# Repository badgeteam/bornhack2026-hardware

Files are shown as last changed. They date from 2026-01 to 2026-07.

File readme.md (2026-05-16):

# Cyber Ægg

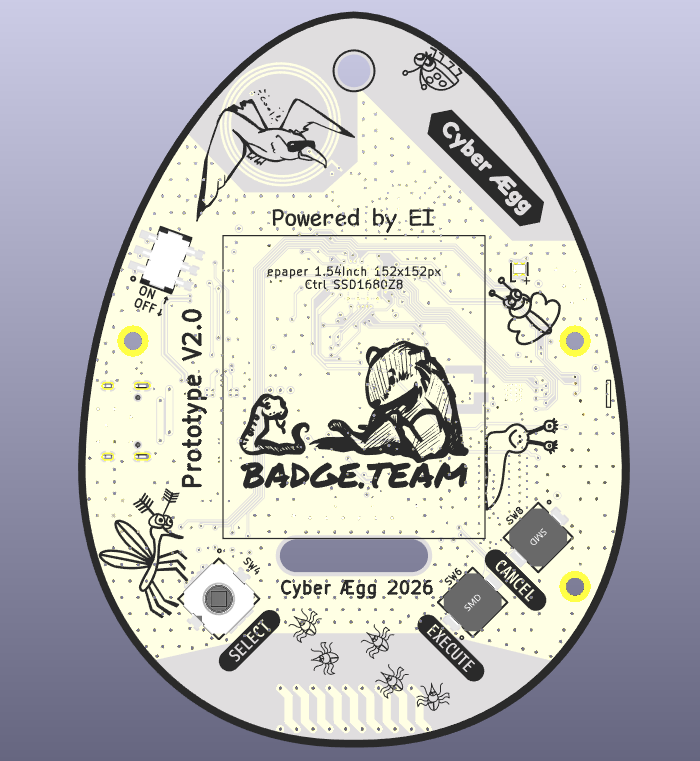
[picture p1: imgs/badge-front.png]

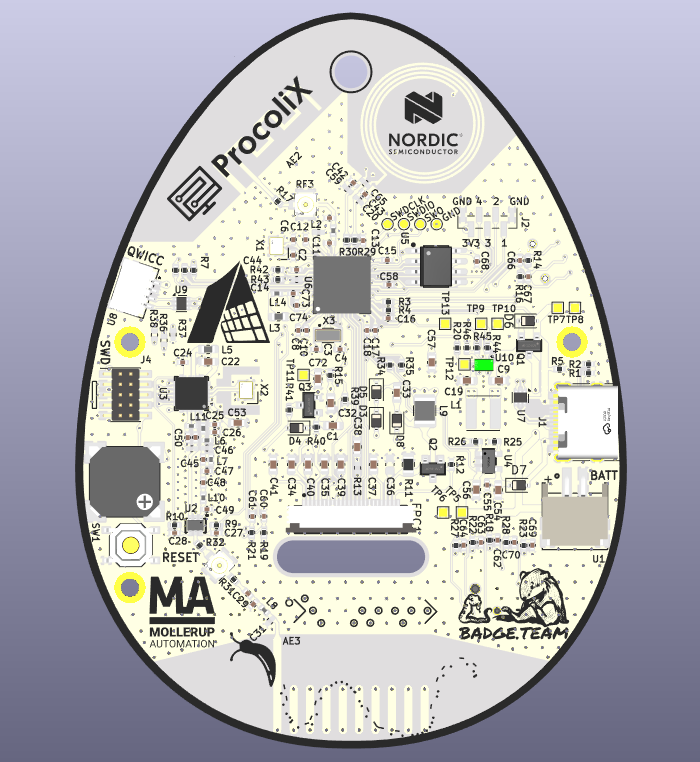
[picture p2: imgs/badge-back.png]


## Introduction

The badge is intended to be a low power LoRa device, that should be able to at least run for the whole duration of the BornHack camp on one battery charge (One week).
At least that is one of our design goals, lot's of hours chasing down power use in both the hardware and the software are still ahead of us, when measurements have been done I'll share them in the Badge.Team Discord.

At this moment the design is at prototype stage one, and is not fully developed.

For example the NFC, LoRa and Bluetooth circuits still have IPEX connectors integrated to make tuning the circuits easier.

Also certain aspects, especially the on PCB antennas should at least work, but how well, we do not know yet.

Long story short, consider this design BETA, and do not order your own boards yet. (Or if you do, you are on your own.)

## Functionality

The is designed with MeshCore in mind, to connect up to a smart phone using Bluetooth and connect to the greater MeshCore network using the on PCB LoRa circuit.

To provide some extra camp fun, we hope the communication technologies combined with the NFC tag functionality will result in some really cool location based games that will run on the badge.
For now the game ideas being worked out, and it's up to the game team of BornHack what they share.

### Display

For now the e-paper display is designed in from SWI, model number: SG0154BNS800F35HP

The display has a 1.54Inch size with 152x152 pixels.

These displays have the [SSD1680Z8](https://cdn-learn.adafruit.com/assets/assets/000/097/631/original/SSD1680_Datasheet.pdf?1607625960) controller controller IC.

### Manual input

Because the Cyber Ægg badge is inspired by the 90's Tamagotchi egg shaped game, the buttons are named the same.

| button name | function |
| --- | --- |
| Select | Navigate through the menu options |
| Execute | Start the option under the cursor |
| Cancel | Cancel current operation |

In order to make navigation a more intuitive, the select button has been upgraded to a joystick + button.

### Bluetooth

The Bluetooth implementation on this board is provided by the NRF52840 MCU.
Texas instruments has released a design for a 2.4GHz antenna, the antenna is provided as a Footprint included with Kicad 9.0.

#### BlueTooth Antenna

Bluetooth is using 2.4GHz, and a PCB antenna suitable for this frequency band is integrated into the PCB.
The design used is available in KiCAD 9 in the standard library and is originally by Texas instruments.

The documentation for the antenna can be found here : [swra228.pdf](https://www.ti.com/lit/an/swra228c/swra228c.pdf)

### LoRa

LoRa is provided by a separate SX1262 IC, with a tuning circuit as specified by the data sheet and implementation notes provided by Semtech.

The document that specifies the layout/balun/matching circuit for the sx1262 is named *"AN1200.54"* and can be found at [this page](https://www.semtech.com/products/wireless-rf/lora-connect/sx1261)

#### Lora Antenna

The LoRa antenna is also a Texas instruments design, the specifications can be found here [swra416](https://www.ti.com/lit/an/swra416/swra416.pdf)

### NFC

NRF is again provided by a PHY in the NRF82840 core, which drives a resonant circuit consisting of 2 (eventually) capacitors, and a CPB coil.

The NRF52840 only supports TAG functionality no reader functionality.

The coil in this design has a inductance of around 2.8uH, which together with the capacitors and the paracytics (both capacitance and inductance) should form a tank circuit that matches the 13.56MHz for interacting with an NRC reader.

### QWIIC

The QWIIC port is a standardized connector utilizing I2C, it's included on the badge because many boards have been produced for this [standard](https://www.sparkfun.com/qwiic) setup by Sparkfun.

Pins used for the SDA and SCL pins are listed below.

Two 10k pull up resistors are provided on the board, when the capacitance is too high on the I2C lines, the internal pull-ups can also be enabled (the provide an extra 10k pull-up resistance).

## Production

!! Very important: The vias on the board must be filled with epoxy and capped for proper soldering. !!

### JLCPCB production settings

#### PCB production settings

| Item | Value |
| :--- | :--- |
| Base Material | FR-3 |
| Product type | Industrial / Consumer electronics  |
| PCB Thickness | 1.6mm |
| Material Type | FR4 TG135 |
| Gold thickness | 1 U" |
| Outer Copper Weight | 1 oz |
| Inner Copper Weight | 0.5 oz |
| Surface Finish | ENIG |
| Specify Stackup | JLC0461H-7628 (Prepreg 0.21mm, Core 1.065mm) |
| Impedance Control | No requirement |
| Via Covering | Epoxy Filled & Capped |
| Via Plating Method | Horizontal Electroless Copper Plating |
| Min via hole size/diameter | 0.2mm |
| Board outline Tolerance | 0.2mm |
 
#### PCBA production settings

| Item | Value |
| :--- | :---- |
| PCBA Type | Standard |
| Assembly Side | Both Sides |
| Parts Selection | By Customer |

## Pinout

| Ball (aQFN73) | nRF pin | Pin type(s) | Project net  | Project function |
| :--- | :--- | :--- | :--- | :--- |
| A12 | P0.02 AIN0 | Digital I/O Analog input | LED_BLUE | LED blue (active low, GPIO output) |
| B13 | P0.03 AIN1 | Digital I/O Analog input | LORA_MISO | LoRa (SX1262) SPI MISO (GPIO input) |
| J1 | P0.04 AIN2 | Digital I/O Analog input | LORA_RF_SW | LoRa RF switch control (GPIO output) |
| K2 | P0.05 AIN3 | Digital I/O Analog input | BAT_CHARGE | Charge status: low when charging (GPIO input) |
| L1 | P0.06 | Digital I/O | BTN_CANCEL | Button: cancel (active low, GPIO input) |
| M2 | P0.07 | Digital I/O | BAT_V_READ | Battery read enable: pull low to read VBAT (GPIO output) |
| N1 | P0.08 | Digital I/O | EPD_SCK | EPD (SSD1675) SPI SCK (GPIO output) |
| M24 | P0.09 NFC1 | NFC I/O | NFC1 | NFC antenna connection |
| L24 | P0.10 NFC2 | NFC I/O | NFC2 | NFC antenna connection |
| U1 | P0.11 | Digital I/O | EPD_RESET | EPD (SSD1675) reset (GPIO output) |
| V2 | P0.12 | Digital I/O | EPD_DC | EPD (SSD1675) data/command (GPIO output) |
| W1 | P0.13 | Digital I/O | BUZZER | Buzzer square wave output (PWM/GPIO output) |
| X2 | P0.14 | Digital I/O | EPD_BUSY | EPD (SSD1675) busy signal (GPIO input) |
| AC12 | P0.15 | Digital I/O | GPIO_1 | General purpose I/O 1 |
| AB13 | P0.16 | Digital I/O | GPIO_2 | General purpose I/O 2 |
| AC11 | P0.17 | Digital O | PS_SYNC | Power mode buck/boost hi/low power mode |
| AC13 | P0.18 nRESET | Digital O | MCU_RESET | nRESET (active low) |
| AB11 | P0.19 | Digital I/O | GPIO_3 | General purpose I/O 3 |
| AC9 | P0.20 | Digital I/O (QSPI) | FLASH_IO0 | QSPI Flash IO0/D0 |
| AB9 | P0.21 | Digital I/O (QSPI) | FLASH_SCK | QSPI Flash clock (GPIO output) |
| AC7 | P0.22 | Digital I/O (QSPI) | FLASH_IO2 | QSPI Flash IO2/D2 |
| AB7 | P0.23 | Digital I/O (QSPI) | FLASH_IO3 | QSPI Flash IO3/D3 |
| AC5 | P0.24 | Digital I/O (QSPI) | FLASH_IO1 | QSPI Flash IO1/D1 |
| AB5 | P0.25 | Digital I/O (QSPI) | FLASH_CSN | QSPI Flash chip select (active low, GPIO output) |
| G1 | P0.26 | Digital I/O | BTN_EXECUTE  | Button: execute (active low, GPIO input) |
| H2 | P0.27 | Digital I/O | EPD_MOSI | EPD (SDD1675) SPI MOSI (GPIO output) |
| B11 | P0.28 AIN4 | Digital I/O Analog input | LORA_BUSY | LoRa (SX1262) busy (GPIO input) |
| A10 | P0.29 AIN5 | Digital I/O Analog input | LORA_DIO1 | LoRa (SX1262) DIO1 IRQ (GPIO input) |
| B9 | P0.30 AIN6 | Digital I/O Analog input | LORA_RST | LoRa (SX1262) reset (GPIO output) |
| A8 | P0.31 AIN7 | Digital I/O Analog input | VBAT_V | Battery voltage sense (ADC input) |
| AD22 | P1.00 | SWD | P1.00_SWO | SWO pin SWD NRF52840 |
| Y23 | P1.01 | Digital I/O | JOY_RIGHT | Joystick: right (active low, GPIO input) |
| W24 | P1.02 | Digital I/O | JOY_FIRE | Joystick: fire (active low, GPIO input) |
| V24 | P1.03 | Digital I/O | JOY_DOWN | Joystick: down (active low, GPIO input) |
| U24 | P1.04 | Digital I/O | JOY_UP | Joystick: up (active low, GPIO input) |
| T23 | P1.05 | Digital I/O | JOY_LEFT | Joystick: left (active low, GPIO input) |
| P23 | P1.07 | Digital I/O | LED_RED | LED red (active low, GPIO output) |
| P2 | P1.08 | Digital I/O | EPD_MOSI | EPD (SSD1675) MISO/MOSI line EPD |
| R1 | P1.09 | Digital I/O | EPD_CSN | EPD (SSD1675) SPI CSN (active low, GPIO output) |
| A20 | P1.10 | Digital I/O | QWIIC_SDA | Qwiic I²C SDA (open-drain) |
| B19 | P1.11 | Digital I/O | QWIIC_SCL | Qwiic I²C SCL (open-drain) |
| B17 | P1.12 | Digital I/O | LORA_NSS | LoRa (SX1262) SPI NSS/CS (active low, GPIO output) |
| A16 | P1.13 | Digital I/O | LORA_SCK | LoRa (SX1262) SPI SCK (GPIO output) |
| B15 | P1.14 | Digital I/O | LORA_MOSI | LoRa (SX1262) SPI MOSI (GPIO output) |
| A14 | P1.15 | Digital I/O | LED_GREEN | LED green (active low, GPIO output) |
| AD6 | D+ | USB | USB_D+ | USB data + |
| AD4 | D- | USB | USB_D- | USB data - |

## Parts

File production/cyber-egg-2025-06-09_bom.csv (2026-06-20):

Designator | Footprint | Quantity | Value | LCSC Part #
BUZZER1 | BUZ-SMD_4P-L8.5-W8.5-P8.50-BR | 1 | MLT-8530 | C94599
C1, C33, C34, C35, C37, C38, C39, C40, C53, C72 | 0603 | 10 | 1uF | C5199872
C10, C24, C55, C58, C60, C61, C62, C63, C64, C68, C69, C70 | 0402 | 12 | 100nF | C1525
C12 | 0402 | 1 | 100pF | C1546
C13 | 0402 | 1 | 820pF | C1543
C15, C18, C44, C66, C67, C8 | 0402 | 6 | 2.2uF | C12530
C16, C17 | 0402 | 2 | 4.7uF | C23733
C19, C57 | 0603 | 2 | 22uF | C59461
C2, C6 | 0402 | 2 | 18pF | C1549
C22, C41 | 0603 | 2 | 470nF | C1623
C25, C73 | 0402 | 2 | 47nF | C82219
C26, C29 | 0402 | 2 | 47pF | C472454
C27, C28 | 0402 | 2 | 1nF | C1523
C3, C4 | 0402 | 2 | 12pF | C1547
C30, C50 | 0402 | 2 | 1.8pF | C22374861
C32 | 0603 | 1 | 4.7uF | C69335
C42, C43 | 0402 | 2 | 68pF | C389103
C45 | 0402 | 1 | 3.3pF | C2941931
C47 | 0402 | 1 | 5.6pF | C16193755
C48 | 0402 | 1 | 39pF | C86288
C49 | 0402 | 1 | 2.2pF | C325452
C5 | 0402 | 1 | .5pF | C1544
C51 | 0402 | 1 | 2.4pF | C48346
C54, C56, C9 | 0603 | 3 | 10uF | C19702
C7 | 0402 | 1 | .8pF | C285068
C74 | 0402 | 1 | 1uF | C52923
D3, D5, D8 | D_SOD-323 | 3 | B0530WS | C22466873
D4, D6, D7 | D_SOD-323 | 3 | 1N5819WS | C191023
FPC1 | FPC-SMD_24P-P0.50_GT-F0501SR10-24S1101 | 1 | GT-F0501SR10-24S1101 | C22380687
J1 | USB_C_Receptacle_HRO_TYPE-C-31-M-12 | 1 | USB device | C165948
J4 | SWD_PinHeader_2x05_P1.27mm_Vertical_SMD | 1 | Conn_02x05_Odd_Even | C27985146
L1 | L_Vishay_IFSC-1515AH_4x4x1.8mm | 1 | 0.47uH A-sat 5.4 DCR 7.6 mOhm | C7497069
L10, L2 | 0402 | 2 | 4.7nH | C86065
L11, R17, R29, R3, R30, R31, R32, R4 | 0402 | 8 | 0 | C17168
L12, L14 | 0402 | 2 | 15nH | C381880
L3 | 0603 | 1 | 10uH | C1035
L5 | 0603 | 1 | 15uH | C486329
L6 | 0402 | 1 | 47nH | C27151
L7 | 0402 | 1 | 2.5nH | C778764
L8 | 0402 | 1 | 7.5nH | C98001
L9 | 1210 | 1 | 47uH | C83083
LED1 | LED-ARRAY-SMD_4P-L1.6-W1.5-BR_XL-1615RGBC-RF | 1 | XL-1615RGBC-RF | C965840
Q1 | SOT-23-3_L2.9-W1.3-P1.90-LS2.4-BR | 1 | JSM2301S | C916399
Q2 | SOT-23-3_L2.9-W1.3-P1.90-LS2.4-BR | 1 | AP2302B | C406812
Q3 | SOT-23-3_L2.9-W1.3-P1.90-LS2.4-BR | 1 | SI2302_C5296725 | C5296725
R1, R2 | 0402 | 2 | 5k1 | C25905
R10, R41, R47, R9 | 0402 | 4 | 100 | C25076
R11 | 0805 | 1 | 2.2 | C2907304
R12, R5 | 0402 | 2 | 100k | C25741
R14, R16, R24 | 0402 | 3 | 1k | C11702
R15 | 0402 | 1 | 47k | C25792
R18, R19, R21, R22, R23, R26, R27, R28, R7 | 0402 | 9 | 10k | C25744
R20 | 0402 | 1 | 3.3k | C25890
R25, R6, R8 | 0402 | 3 | 2k | C4109
R34, R39, R40, R44 | 0402 | 4 | 1M | C26083
R35 | 0402 | 1 | 510k | C25564
R42, R43 | 0402 | 2 | 4.7k | C25900
R45 | 0402 | 1 | 511k | C64042
R46 | 0402 | 1 | 91k | C4147
RF1, RF3 | IPEX-SMD_3P-L2.6-W2.6-LS3.0_RF1200001R | 2 | A-IPEX1-1.25A | C22467595
SW1 | SW-SMD_4P-L5.1-W5.1-P3.70-LS6.5-TL_H1.5 | 1 | RESET | C318884
SW3 | SW-SMD_MS-22D28-G020 | 1 | MS-22D28-G020 | C963205
SW4 | SW-SMD_6P-L7.0-W7.0-P1.40-LS7.4-TL | 1 | 7*7*5-6P WX | C2858286
SW6, SW8 | KEY-SMD_2P-L6.0-W6.0-P6.00 | 2 | TS3425PA 160GF 098 | C115348
U1 | CONN-SMD_PH-2AWB | 1 | PH-2AWB | C20598817
U10 | DSBGA-15_L2.3-W1.3-R5-C3-P0.40-TL | 1 | TPS63805YFFR | C2879615
U2 | SOT-363-6_L2.0-W1.3-P0.65-LS2.1-BL | 1 | ZHHXDZ HXCKRF2179MM26-C4 | C49010109
U3 | QFN-24_L4.0-W4.0-P0.50-BL-EP2.6 | 1 | SX1262IMLTRT | C191341
U4 | SOT-23-5_L2.9-W1.6-P0.95-LS2.8-BL | 1 | XT4054K421MR-G | C141405
U5 | SOIC-8_L4.9-W3.9-P1.27-LS6.0-BL | 1 | ZD25WQ16CTIGT | C5353550
U6 | XCVR_NRF52840-QIAA-R | 1 | NRF52840-QIAA-R | C190794
U7, U9 | SOT-666 | 2 | USBLC6-2P6 | C22390016
U8 | CONN-SMD_HCZZ0032-4 | 1 | HCZZ0032-4 | C7433425
X1, X2 | CRYSTAL-SMD_4P-L2.0-W1.6-BL | 2 | S201632M10PF10PPM 32MHz | C7420782
X3 | Crystal_SMD_3215-2Pin_3.2x1.5mm | 1 | 32.768KHz | C95361

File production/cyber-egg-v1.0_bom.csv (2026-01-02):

Designator | Footprint | Quantity | Value | LCSC Part #
C1, C27, C28 | 0402 | 3 | 1nF | C1523
C10, C14, C24, C55, C57, C64, C68 | 0402 | 7 | 100nF | C1525
C12 | 0402 | 1 | 100pF | C1546
C13 | 0402 | 1 | 820pF | C1543
C15, C16, C17, C18, C19, C44, C66, C67, C8 | 0402 | 9 | 2.2uF | C12530
C2, C21, C23, C6 | 0402 | 4 | 10pF | C32949
C22 | 0603 | 1 | 470nF | C1623
C25, C73 | 0402 | 2 | 47nF | C82219
C26, C29 | 0402 | 2 | 47pF | C472454
C3, C4 | 0402 | 2 | 10n | C1524
C30, C31 | 0402 | 2 | 3.6pF | C52052
C32 | 0603 | 1 | 4.7uF | C69335
C33, C34, C35, C36, C37, C38, C39, C40, C53, C72, C74 | 0603 | 11 | 1uF | C5199872
C41 | 0603 | 1 | 470n | C1623
C42, C43 | 0402 | 2 | 12pF | C161304
C45 | 0402 | 1 | 3pF | C41361091
C47 | 0402 | 1 | 5.6pF | C16193755
C48 | 0402 | 1 | 39pF | C86288
C49, C50 | 0402 | 2 | 1.8pF | C22374861
C5 | 0402 | 1 | .5pF | C1544
C51 | 0402 | 1 | 2.4pF | C48346
C54, C56, C60, C61 | 0603 | 4 | 10uF | C19702
C58, C62, C63 | 0805 | 3 | 22uF | C45783
C69, L11, R20, R29, R30, R31, R32 | 0402 | 7 | 0 | C17168
C7 | 0402 | 1 | .8pF | C285068
D1 | D_SOD-323 | 1 | ESD prot. | C22363742
D2 | D_SMA | 1 | B160_13F | C24784
D23, D3, D4, D5 | D_SOD-323 | 4 | NSR0320MW2T1G | C48192
J1 | USB_C_Receptacle_HRO_TYPE-C-31-M-12 | 1 | USB device | C165948
J2 | FPC-SMD_FH12-24S-0.5SH-55 | 1 | E-Paper | C202112
J9 | CONN-SMD_S2B-ZR-SM4A | 1 | Battery | C265329
L1 | ANT-SMD_L3.1-W1.6 | 1 | RFECA3216060A1T | C127620
L10, L2 | 0402 | 2 | 4.7nH | C963987
L12 | 0402 | 1 | 15nH | C381880
L13 | ANT-SMD_L15.0-W3.0 | 1 | 866MHz LoRa antenna | C41368044
L14 | 0402 | 1 | 15nH | C27143
L3 | 0603 | 1 | 10uH | C194437
L4 | IND-SMD_L6.0-W6.0 | 1 | CMLW6028S1R5MST | C431354
L5 | 0603 | 1 | 15uH | C486329
L6 | 0402 | 1 | 47nH | C27151
L7 | 0402 | 1 | 2.5nH | C778764
L8 | 0402 | 1 | 8.2nH | C98003
L9 | 1210 | 1 | 47uH | C83083
LED1 | LED-ARRAY-SMD_4P-L1.6-W1.5-BR_XL-1615RGBC-RF | 1 | XL-1615RGBC-RF | C965840
Q1 | SOT-23-3_L2.9-W1.3-P1.90-LS2.4-BR | 1 | JSM2301S | C916399
Q2 | SOT-23-3_L2.9-W1.3-P1.90-LS2.4-BR | 1 | AP2302B | C406812
R1, R2 | 0402 | 2 | 5k1 | C25905
R10, R9 | 0402 | 2 | 100 | C25076
R11 | 0805 | 1 | 2.2 | C2907304
R12, R5 | 0402 | 2 | 100k | C25530
R14, R16 | 0402 | 2 | 1k | C11702
R15, R18, R19, R21, R22, R23, R26, R27, R28, R7 | 0402 | 10 | 10k | C25744
R17, R33 | 0402 | 2 | 1M | C26083
R24 | 0402 | 1 | 180k | C2909325
R25, R6, R8 | 0402 | 3 | 2k | C4109
R3, R4 | 0402 | 2 | 33 | C25105
RF1, RF2, RF3 | IPEX-SMD_3P-L2.6-W2.6-LS3.0_RF1200001R | 3 | A-IPEX1-1.25A | C22467595
SW1 | SW-SMD_4P-L5.1-W5.1-P3.70-LS6.5-TL_H1.5 | 1 | TS-1187A-B-A-B | C318884
SW2 | SW-SMD_3P-P1.50_L2.7-W6.6 | 1 | SK-3296S-01-L1 | C319020
SW3 | SW-SMD_SKRHABE010 | 1 | SKRHABE010 | C139794
SW6, SW8 | KEY-SMD_2P-L6.0-W6.0-P6.00 | 2 | TS3425PA 160GF 098 | C115348
U2 | SOT-363-6_L2.0-W1.3-P0.65-LS2.1-BL | 1 | TPE4259-63 | C47117600
U3 | QFN-24_L4.0-W4.0-P0.50-BL-EP2.6 | 1 | SX1262IMLTRT | C191341
U4 | SOT-23-5_L2.9-W1.6-P0.95-LS2.8-BL | 1 | XT4054K421MR-G | C141405
U5 | SOIC-8_L4.9-W3.9-P1.27-LS6.0-BL | 1 | ZD25WQ16CTIGT | C5353550
U6 | XCVR_NRF52840-QIAA-R | 1 | NRF52840-QIAA-R | C190794
U7 | VSON-14_L4.0-W3.0-P0.50-BL-EP_TI_DSJ | 1 | TPS63020DSJR | C15483
X1, X2 | CRYSTAL-SMD_4P-L2.0-W1.6-BL | 2 | S201632M10PF10PPM | C7420782
X3 | Crystal_SMD_3215-2Pin_3.2x1.5mm | 1 | 32.768KHz | C95361

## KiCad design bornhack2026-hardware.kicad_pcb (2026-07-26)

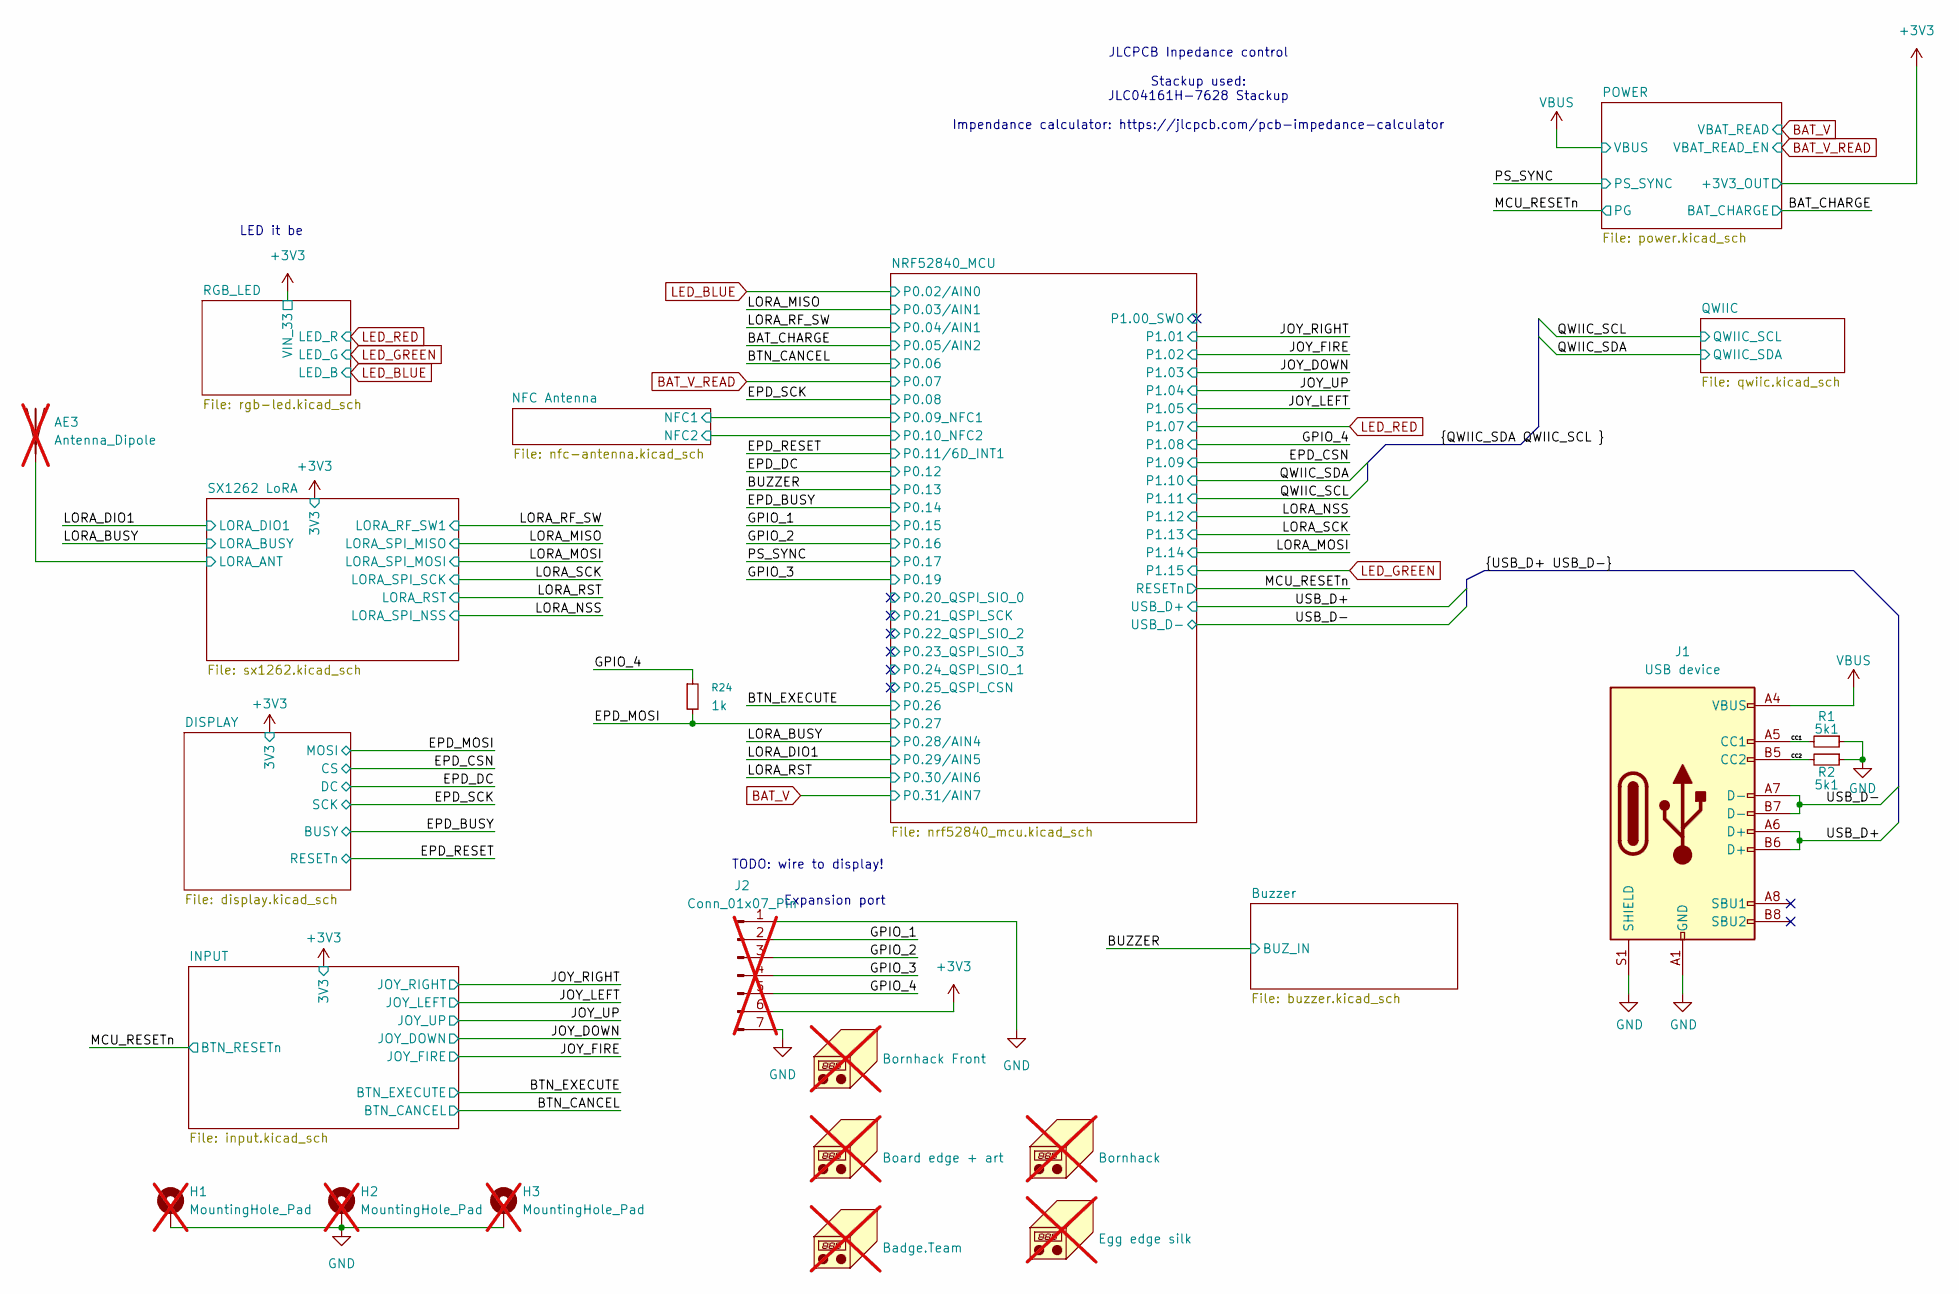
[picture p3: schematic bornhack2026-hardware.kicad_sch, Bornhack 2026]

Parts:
AE3: Antenna_Dipole; Texas_SWRA416_868MHz_915MHz_right_v2; not fitted
H1, H2, H3: MountingHole_Pad; MountingHole_2.2mm_M2_DIN965_Pad; not fitted
J1: USB device; USB_C_Receptacle_HRO_TYPE-C-31-M-12; LCSC C165948
J2: Conn_01x07_Pin; PinHeader_1x07_P1.00mm_Vertical_SMD_Pin1Left; not fitted
N1: Board edge + art; white-egg-svg2shenzhen; not fitted
N2: Badge.Team; stamp; not fitted
N3: Bornhack; bornhack-logo-10mm; not fitted
N4: Egg edge silk; egg-edge-silk; not fitted
N5: Bornhack Front; bornhack-logo-10mm; not fitted
R1, R2: 5k1; R_0402_1005Metric; LCSC C25905
R24: 1k; R_0402_1005Metric; LCSC C11702

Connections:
+3V3: J2.6; also elsewhere on the board
/CC1: J1.A5 (CC1), R1.2
/CC2: J1.B5 (CC2), R2.2
/EPD_MOSI: R24.2; also elsewhere on the board
/GPIO_1: J2.2; also elsewhere on the board
/GPIO_2: J2.3; also elsewhere on the board
/GPIO_3: J2.4; also elsewhere on the board
/GPIO_4: J2.5, R24.1; also elsewhere on the board
/SX1262 LoRA/LORA_ANT: AE3.1 (A_1); also elsewhere on the board
/USB_D+: J1.A6 (D+), J1.B6 (D+); also elsewhere on the board
/USB_D-: J1.A7 (D-), J1.B7 (D-); also elsewhere on the board
GND: H1.1 (1_1), H2.1 (1_1), H3.1 (1_1), J1.A1 (GND), J1.A12 (GND), J1.B1 (GND), J1.B12 (GND), J1.S1 (SHIELD), J2.1, J2.7, R1.1, R2.1; also elsewhere on the board
VBUS: J1.A4 (VBUS), J1.A9 (VBUS), J1.B4 (VBUS), J1.B9 (VBUS); also elsewhere on the board

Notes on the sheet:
TODO: wire to display!
JLCPCB Inpedance control Stackup used: JLC04161H-7628 Stackup Impendance calculator: https://jlcpcb.com/pcb-impedance-calculator
LED it be
Expansion port

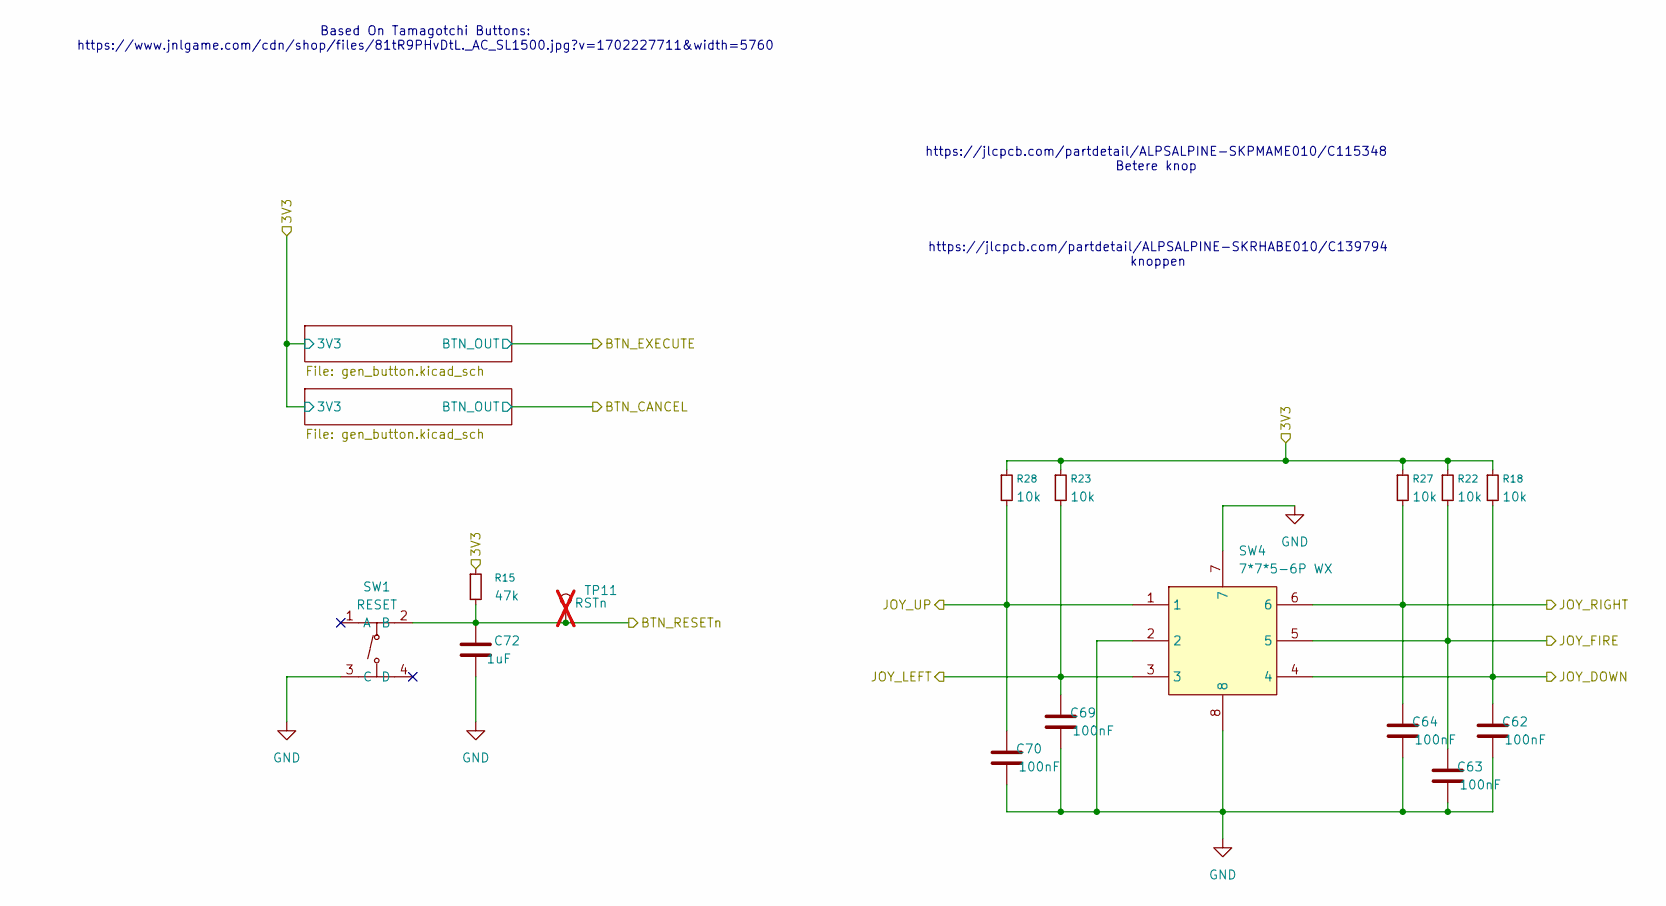
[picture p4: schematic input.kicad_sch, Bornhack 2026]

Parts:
C62, C63, C64, C69, C70: 100nF; C_0402_1005Metric; LCSC C1525
C72: 1uF; C_0603_1608Metric; LCSC C5199872
R15: 47k; R_0402_1005Metric; LCSC C25792
R18, R22, R23, R27, R28: 10k; R_0402_1005Metric; LCSC C25744
SW1: RESET; SW-SMD_4P-L5.1-W5.1-P3.70-LS6.5-TL_H1.5; LCSC Part C318884
SW4: 7*7*5-6P WX; SW-SMD_6P-L7.0-W7.0-P1.40-LS7.4-TL; LCSC C2858286
TP11: TestPoint; TestPoint_Pad_1.0x1.0mm; not fitted

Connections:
+3V3: R15.1, R18.1, R22.1, R23.1, R27.1, R28.1; also elsewhere on the board
/JOY_DOWN: C62.2, R18.2, SW4.4; also elsewhere on the board
/JOY_FIRE: C63.2, R22.2, SW4.5; also elsewhere on the board
/JOY_LEFT: C69.2, R23.2, SW4.3; also elsewhere on the board
/JOY_RIGHT: C64.2, R27.2, SW4.6; also elsewhere on the board
/JOY_UP: C70.2, R28.2, SW4.1; also elsewhere on the board
/MCU_RESETn: C72.2, R15.2, SW1.2 (B), TP11.1 (1_1); also elsewhere on the board
GND: C62.1, C63.1, C64.1, C69.1, C70.1, C72.1, SW1.3 (C), SW4.2, SW4.7, SW4.8; also elsewhere on the board

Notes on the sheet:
https://jlcpcb.com/partdetail/ALPSALPINE-SKPMAME010/C115348 Betere knop
Based On Tamagotchi Buttons: https://www.jnlgame.com/cdn/shop/files/81tR9PHvDtL._AC_SL1500.jpg?v=1702227711&width=5760
https://jlcpcb.com/partdetail/ALPSALPINE-SKRHABE010/C139794 knoppen

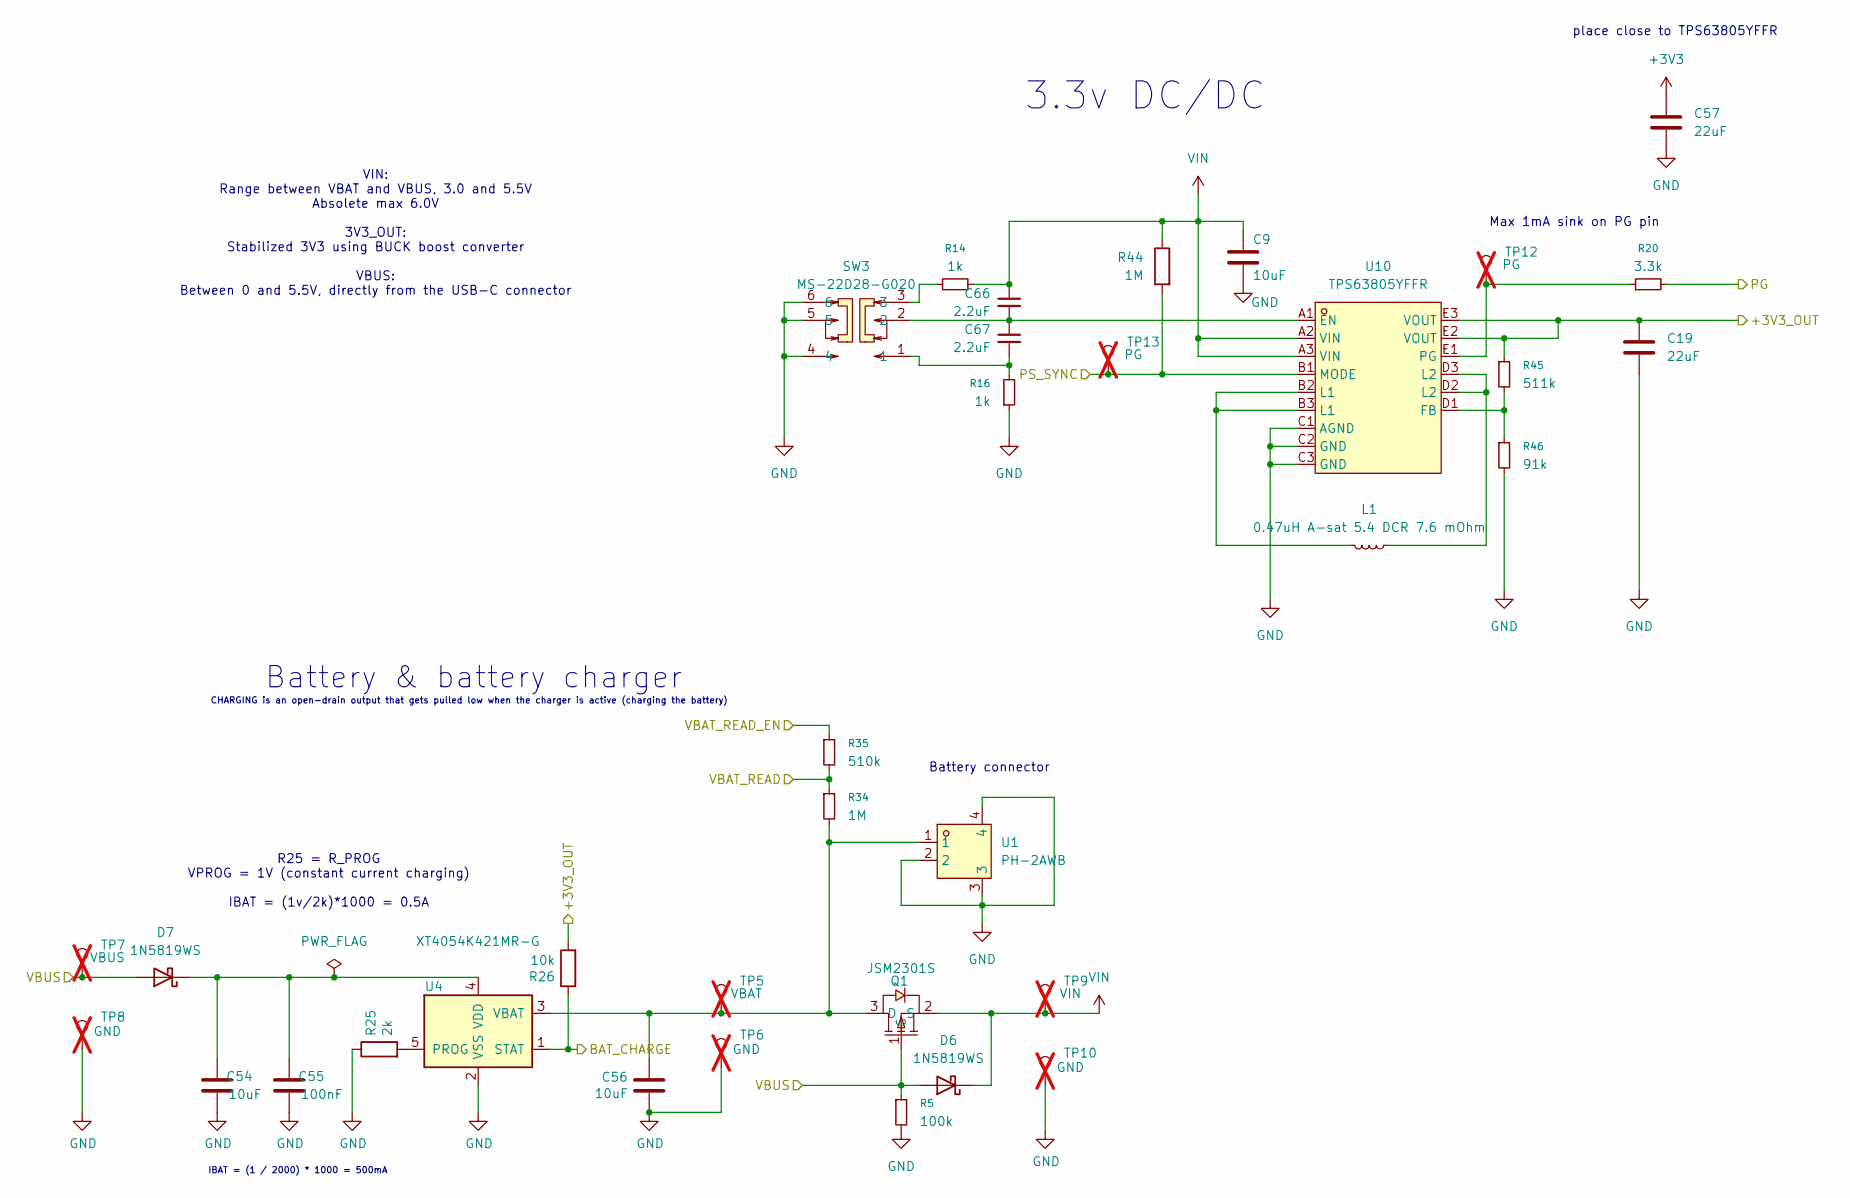
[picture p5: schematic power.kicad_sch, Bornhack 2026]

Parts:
C9, C54, C56: 10uF; C_0603_1608Metric; LCSC C19702
C19, C57: 22uF; C_0603_1608Metric; LCSC C59461
C55: 100nF; C_0402_1005Metric; LCSC C1525
C66, C67: 2.2uF; C_0402_1005Metric; LCSC C12530
D6, D7: 1N5819WS; D_SOD-323; LCSC C191023
L1: 0.47uH A-sat 5.4 DCR 7.6 mOhm; L_Vishay_IFSC-1515AH_4x4x1.8mm; LCSC C7497069
Q1: JSM2301S; SOT-23-3_L2.9-W1.3-P1.90-LS2.4-BR; LCSC Part C916399
R5: 100k; R_0402_1005Metric; LCSC C25741
R14, R16: 1k; R_0402_1005Metric; LCSC C11702
R20: 3.3k; R_0402_1005Metric; LCSC C25890
R25: 2k; R_0402_1005Metric; LCSC C4109
R26: 10k; R_0402_1005Metric; LCSC C25744
R34, R44: 1M; R_0402_1005Metric; LCSC C26083
R35: 510k; R_0402_1005Metric; LCSC C25564
R45: 511k; R_0402_1005Metric; LCSC C64042
R46: 91k; R_0402_1005Metric; LCSC C4147
SW3: MS-22D28-G020; SW-SMD_MS-22D28-G020; LCSC Part C963205
TP5, TP6, TP7, TP8, TP9, TP10, TP12, TP13: TestPoint; TestPoint_Pad_1.0x1.0mm; not fitted
U1: PH-2AWB; CONN-SMD_PH-2AWB; LCSC Part C20598817
U4: XT4054K421MR-G; SOT-23-5_L2.9-W1.6-P0.95-LS2.8-BL; LCSC C141405
U10: TPS63805YFFR; DSBGA-15_L2.3-W1.3-R5-C3-P0.40-TL; LCSC Part C2879615

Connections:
+3V3: C19.1, C57.1, R26.2, R45.1, U10.E2 (VOUT), U10.E3 (VOUT); also elsewhere on the board
/BAT_CHARGE: R26.1, U4.1 (STAT); also elsewhere on the board
/MCU_RESETn: R20.2; also elsewhere on the board
/PS_SYNC: R44.2, TP13.1 (1_1), U10.B1 (MODE); also elsewhere on the board
BAT_V: R34.1, R35.2; also elsewhere on the board
BAT_V_READ: R35.1; also elsewhere on the board
GND: C9.2, C19.2, C54.1, C55.1, C56.2, C57.2, R5.2, R16.1, R25.1, R46.2, SW3.4, SW3.5, SW3.6, TP6.1 (1_1), TP8.1 (1_1), TP10.1 (1_1), U1.2, U1.3, U1.4, U4.2 (VSS), U10.C1 (AGND), U10.C2 (GND), U10.C3 (GND); also elsewhere on the board
unnamed: C67.2, R16.2, SW3.1
unnamed: C54.2, C55.2, D7.1 (K), U4.4 (VDD)
unnamed: L1.1, U10.D2 (L2), U10.D3 (L2)
unnamed: L1.2, U10.B2 (L1), U10.B3 (L1)
unnamed: C56.1, Q1.3 (D), R34.2, TP5.1 (1_1), U1.1, U4.3 (VBAT)
unnamed: R14.2, SW3.3
unnamed: R25.2, U4.5 (PROG)
unnamed: C66.2, C67.1, SW3.2, U10.A1 (EN)
unnamed: R45.2, R46.1, U10.D1 (FB)
unnamed: R20.1, TP12.1 (1_1), U10.E1 (PG)
VBUS: D6.2 (A), D7.2 (A), Q1.1 (G), R5.1, TP7.1 (1_1); also elsewhere on the board
VIN: C9.1, C66.1, D6.1 (K), Q1.2 (S), R14.1, R44.1, TP9.1 (1_1), U10.A2 (VIN), U10.A3 (VIN)

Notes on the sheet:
CHARGING is an open-drain output that gets pulled low when the charger is active (charging the battery)
Max 1mA sink on PG pin
IBAT = (1 / 2000) * 1000 = 500mA
3.3v DC/DC
Battery & battery charger
Battery connector
VIN: Range between VBAT and VBUS, 3.0 and 5.5V Absolete max 6.0V 3V3_OUT: Stabilized 3V3 using BUCK boost converter VBUS: Between 0 and 5.5V, directly from the USB-C connector
place close to TPS63805YFFR
R25 = R_PROG VPROG = 1V (constant current charging) IBAT = (1v/2k)*1000 = 0.5A

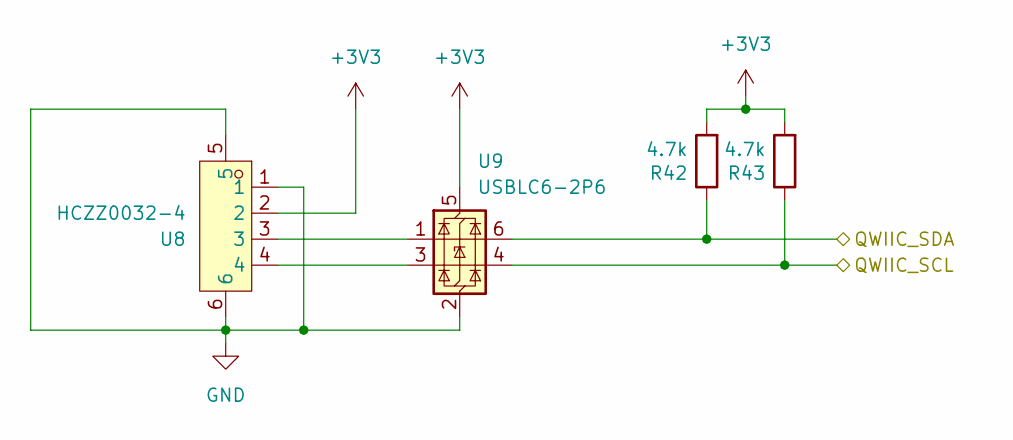
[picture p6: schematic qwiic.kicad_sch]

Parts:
R42, R43: 4.7k; R_0402_1005Metric; LCSC C25900
U8: HCZZ0032-4; CONN-SMD_HCZZ0032-4; LCSC Part C7433425
U9: USBLC6-2P6; SOT-666; LCSC C22390016

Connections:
+3V3: R42.2, R43.2, U8.2, U9.5 (VBUS); also elsewhere on the board
/QWIIC_SCL: R43.1, U9.4 (I/O2); also elsewhere on the board
/QWIIC_SDA: R42.1, U9.6 (I/O1); also elsewhere on the board
GND: U8.1, U8.5, U8.6, U9.2 (GND); also elsewhere on the board
unnamed: U8.3, U9.1 (I/O1)
unnamed: U8.4, U9.3 (I/O2)

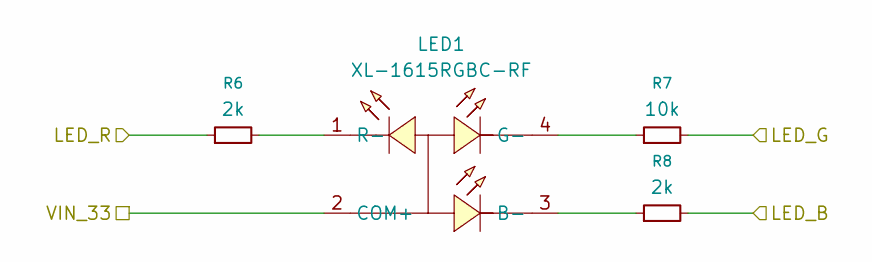
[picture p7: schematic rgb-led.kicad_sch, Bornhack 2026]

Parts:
LED1: XL-1615RGBC-RF; LED-ARRAY-SMD_4P-L1.6-W1.5-BR_XL-1615RGBC-RF; LCSC Part C965840
R6, R8: 2k; R_0402_1005Metric; LCSC C4109
R7: 10k; R_0402_1005Metric; LCSC C25744

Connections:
+3V3: LED1.2 (COM+); also elsewhere on the board
LED_BLUE: R8.2; also elsewhere on the board
LED_GREEN: R7.2; also elsewhere on the board
LED_RED: R6.1; also elsewhere on the board
unnamed: LED1.3 (B-), R8.1
unnamed: LED1.4 (G-), R7.1
unnamed: LED1.1 (R-), R6.2

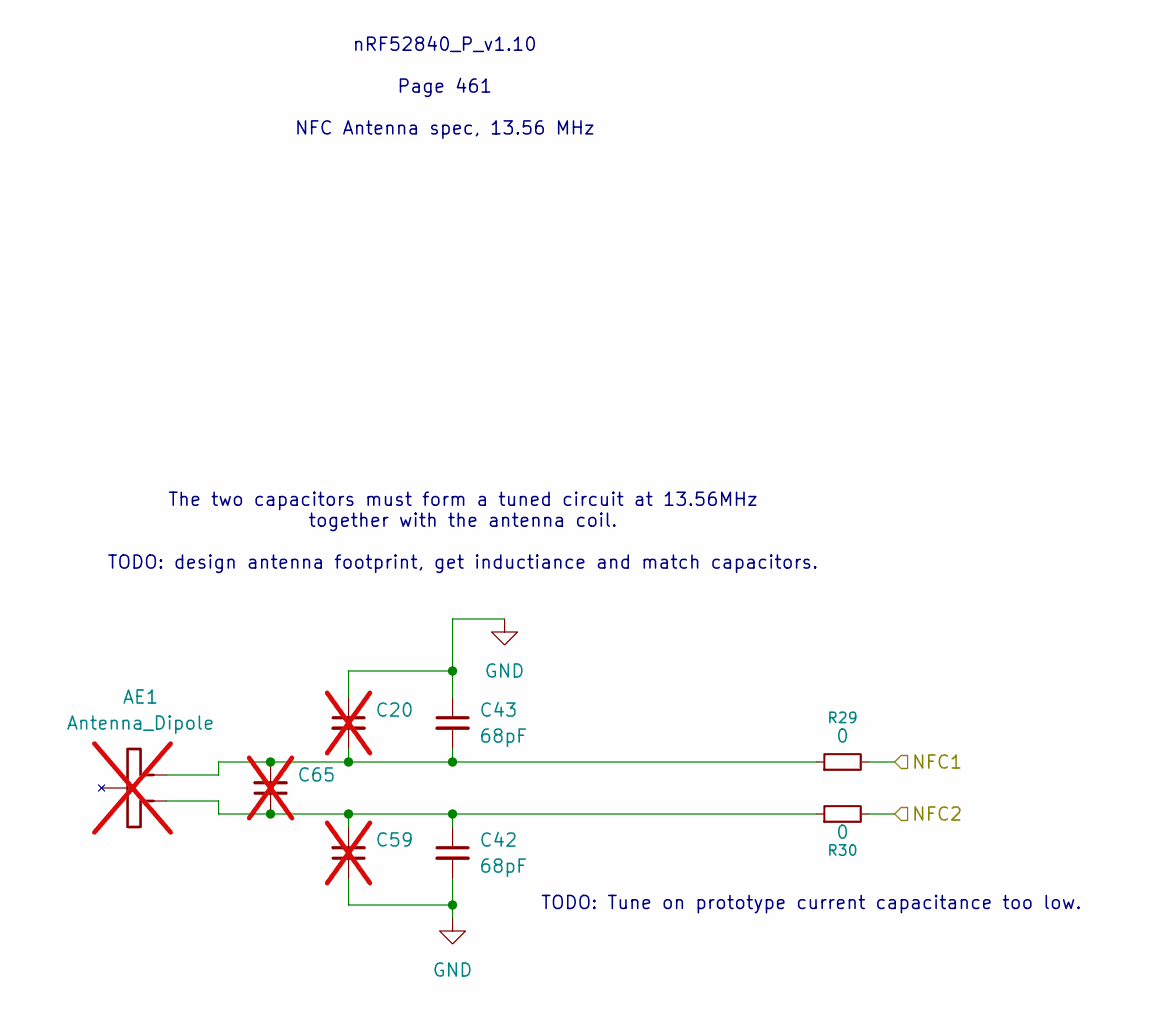
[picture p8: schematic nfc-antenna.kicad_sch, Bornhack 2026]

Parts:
AE1: Antenna_Dipole; NFC_2.8uH_COIL; not fitted
C20, C59, C65: C_0402_1005Metric; not fitted
C42, C43: 68pF; C_0402_1005Metric; LCSC C389103
R29, R30: 0; R_0402_1005Metric; LCSC C17168

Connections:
/NFC Antenna/NFC1: R29.2; also elsewhere on the board
/NFC Antenna/NFC2: R30.2; also elsewhere on the board
GND: C20.1, C42.2, C43.1, C59.1; also elsewhere on the board
unnamed: AE1.1, C42.1, C59.2, C65.1, R30.1
unnamed: AE1.2, C20.2, C43.2, C65.2, R29.1

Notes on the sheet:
nRF52840_P_v1.10 Page 461 NFC Antenna spec, 13.56 MHz
TODO: Tune on prototype current capacitance too low.
The two capacitors must form a tuned circuit at 13.56MHz together with the antenna coil. TODO: design antenna footprint, get inductiance and match capacitors.

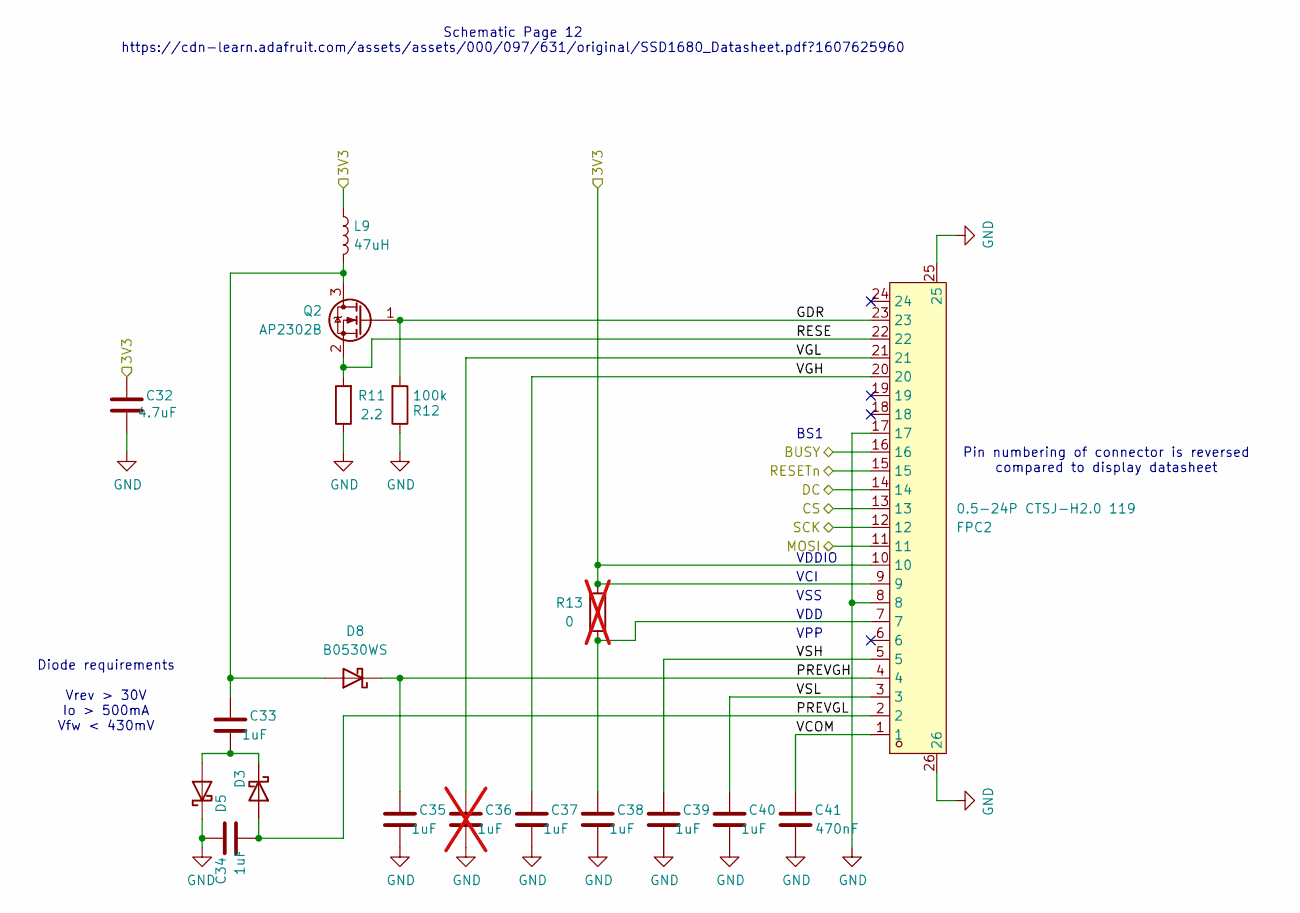
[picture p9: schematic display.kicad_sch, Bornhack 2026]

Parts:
C32: 4.7uF; C_0603_1608Metric; LCSC C69335
C33, C34, C35, C37, C38, C39, C40: 1uF; C_0603_1608Metric; LCSC C5199872
C36: 1uF; C_0603_1608Metric; LCSC C15849; not fitted
C41: 470nF; C_0603_1608Metric; LCSC C1623
D3, D5, D8: B0530WS; D_SOD-323; LCSC C22466873
FPC2: 0.5-24P CTSJ-H2.0 119; FPC-SMD_24P-P0.50_SHOU-HAN_CTSJ-H2.0; LCSC Part C2858299
L9: 47uH; L_1210_3225Metric; LCSC C83083
Q2: AP2302B; SOT-23-3_L2.9-W1.3-P1.90-LS2.4-BR; LCSC C406812
R11: 2.2; R_0805_2012Metric; LCSC C2907304
R12: 100k; R_0402_1005Metric; LCSC C25741
R13: 0; R_0402_1005Metric; not fitted

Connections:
+3V3: C32.2, FPC2.9, FPC2.10, L9.1, R13.1; also elsewhere on the board
/DISPLAY/GDR: FPC2.23, Q2.1 (G), R12.2
/DISPLAY/PREVGH: C35.2, D8.1 (K), FPC2.4
/DISPLAY/PREVGL: C34.1, D3.2 (A), FPC2.2
/DISPLAY/RESE: FPC2.22, Q2.2 (S), R11.2
/DISPLAY/VCOM: C41.2, FPC2.1
/DISPLAY/VGH: C37.2, FPC2.20
/DISPLAY/VGL: C36.2, FPC2.21
/DISPLAY/VSH: C39.2, FPC2.5
/DISPLAY/VSL: C40.2, FPC2.3
/EPD_BUSY: FPC2.16; also elsewhere on the board
/EPD_CSN: FPC2.13; also elsewhere on the board
/EPD_DC: FPC2.14; also elsewhere on the board
/EPD_MOSI: FPC2.11; also elsewhere on the board
/EPD_RESET: FPC2.15; also elsewhere on the board
/EPD_SCK: FPC2.12; also elsewhere on the board
GND: C32.1, C34.2, C35.1, C36.1, C37.1, C38.1, C39.1, C40.1, C41.1, D5.1 (K), FPC2.8, FPC2.17, FPC2.25, FPC2.26, R11.1, R12.1; also elsewhere on the board
unnamed: C38.2, FPC2.7, R13.2
unnamed: C33.1, D3.1 (K), D5.2 (A)
unnamed: C33.2, D8.2 (A), L9.2, Q2.3 (D)

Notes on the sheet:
Diode requirements Vrev > 30V Io > 500mA Vfw < 430mV
VDDIO
Pin numbering of connector is reversed compared to display datasheet
VPP
VDD
Schematic Page 12 https://cdn-learn.adafruit.com/assets/assets/000/097/631/original/SSD1680_Datasheet.pdf?1607625960
VSS
BS1
VCI

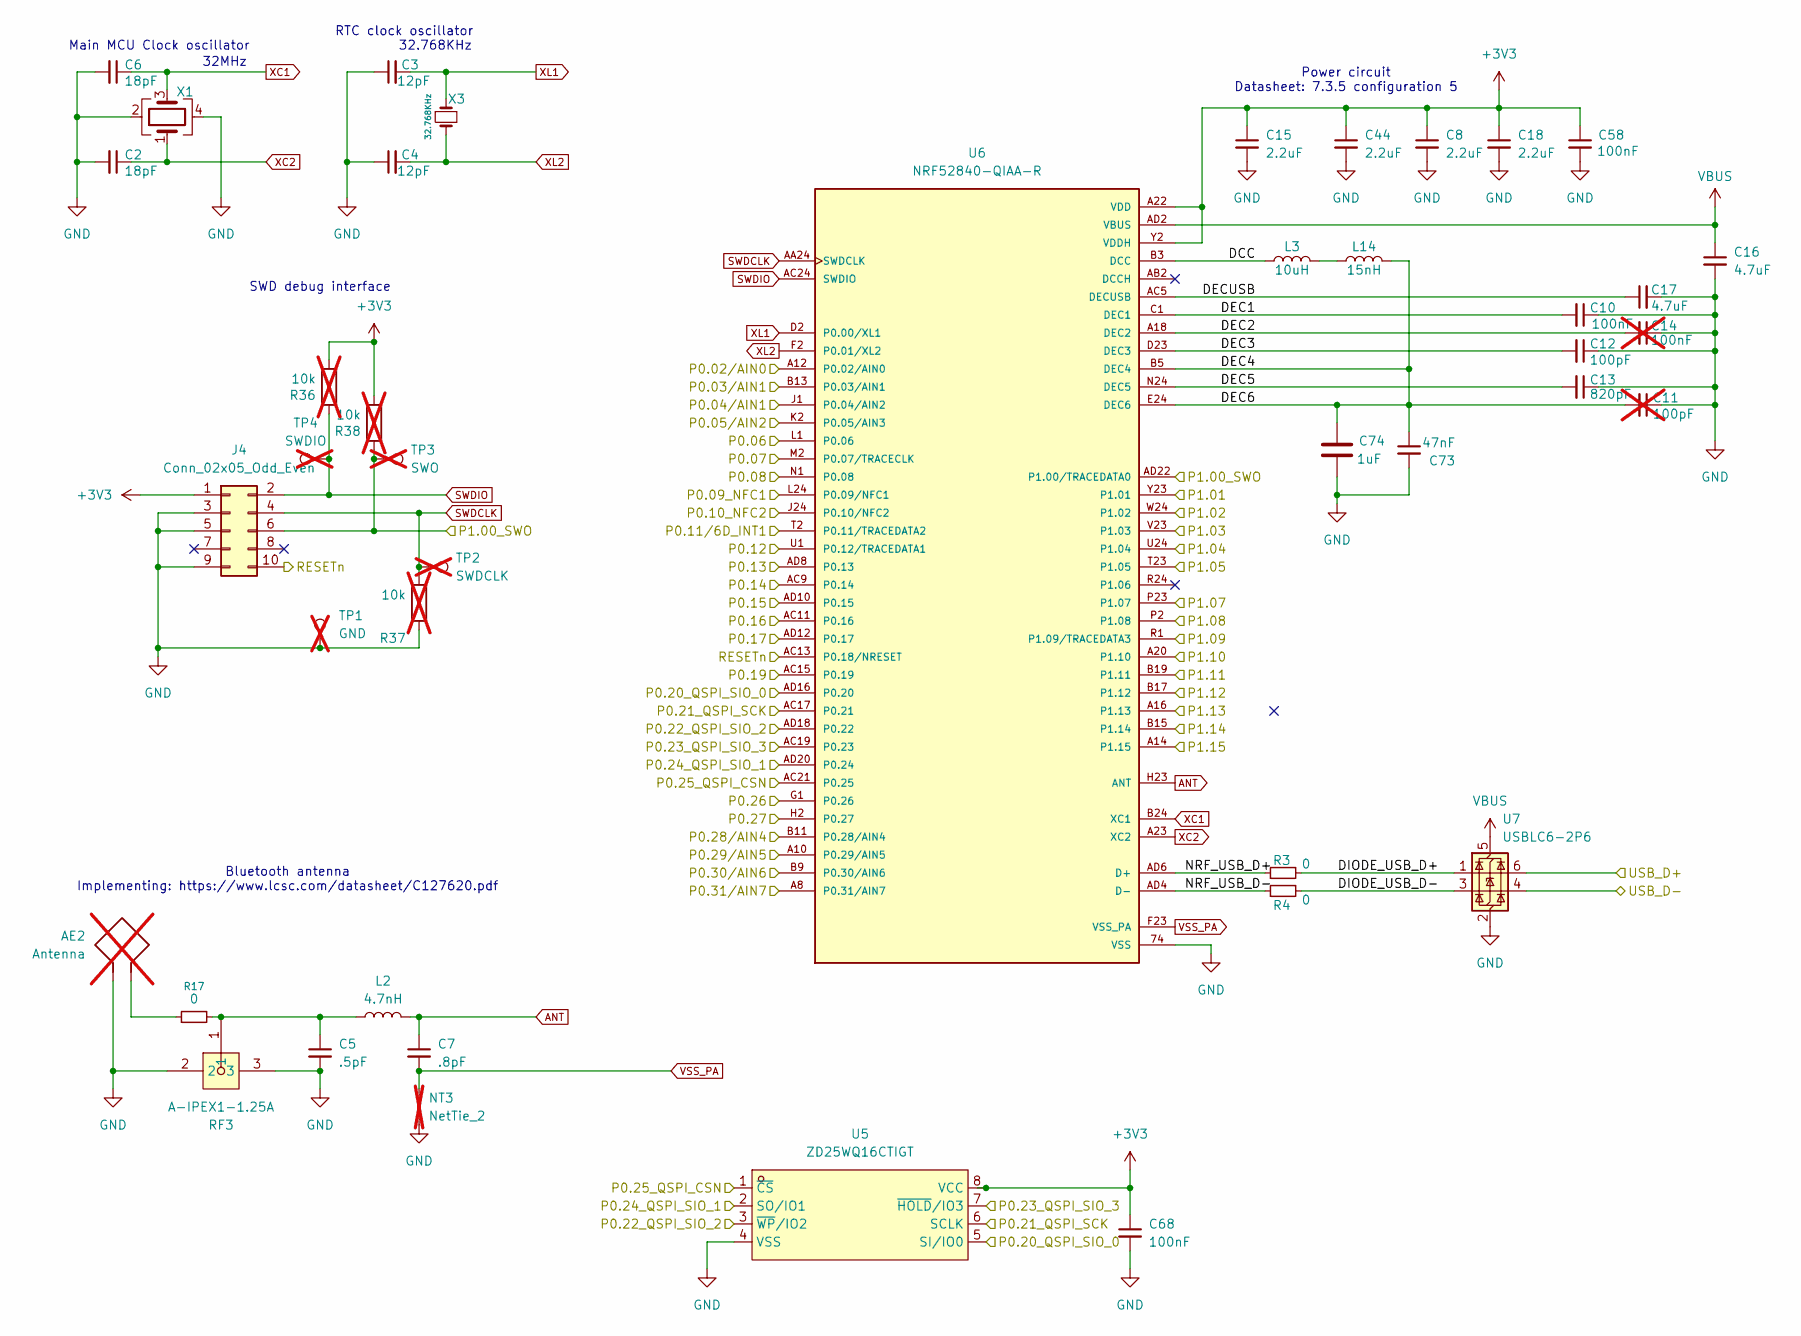
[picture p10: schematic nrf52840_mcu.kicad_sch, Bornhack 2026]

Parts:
AE2: Antenna; Texas_SWRA117D_2.4GHz_Right; not fitted
C2, C6: 18pF; C_0402_1005Metric; LCSC C1549
C3, C4: 12pF; C_0402_1005Metric; LCSC C1547
C5: .5pF; C_0402_1005Metric; LCSC C1544
C7: .8pF; C_0402_1005Metric; LCSC C285068
C8, C15, C18, C44: 2.2uF; C_0402_1005Metric; LCSC C12530
C10, C58, C68: 100nF; C_0402_1005Metric; LCSC C1525
C11: 100pF; C_0402_1005Metric; LCSC C1546; not fitted
C12: 100pF; C_0402_1005Metric; LCSC C1546
C13: 820pF; C_0402_1005Metric; LCSC C1543
C14: 100nF; C_0402_1005Metric; LCSC C1525; not fitted
C16, C17: 4.7uF; C_0402_1005Metric; LCSC C23733
C73: 47nF; C_0402_1005Metric; LCSC C82219
C74: 1uF; C_0402_1005Metric; LCSC C52923
J4: Conn_02x05_Odd_Even; PinHeader_2x05_P1.27mm_Vertical_SMD; LCSC C27985146
L2: 4.7nH; L_0402_1005Metric; LCSC C86065
L3: 10uH; L_0603_1608Metric; LCSC C1035
L14: 15nH; L_0402_1005Metric; LCSC C381880
NT3: NetTie_2; NetTie-2_SMD_Pad0.5mm; not fitted
R3, R4, R17: 0; R_0402_1005Metric; LCSC C17168
R36, R37, R38: 10k; R_0402_1005Metric; LCSC C25744; not fitted
RF3: A-IPEX1-1.25A; IPEX-SMD_3P-L2.6-W2.6-LS3.0_RF1200001R; LCSC Part C22467595
TP1: GND; TestPoint_Pad_D1.0mm; not fitted
TP2: SWDCLK; TestPoint_Pad_D1.0mm; not fitted
TP3: SWO; TestPoint_Pad_D1.0mm; not fitted
TP4: SWDIO; TestPoint_Pad_D1.0mm; not fitted
U5: ZD25WQ16CTIGT; SOIC-8_L4.9-W3.9-P1.27-LS6.0-BL; LCSC Part C5353550
U6: NRF52840-QIAA-R; XCVR_NRF52840-QIAA-R; PARTREV v1.1; LCSC C190794
U7: USBLC6-2P6; SOT-666; LCSC C22390016
X1: S201632M10PF10PPM 32MHz; CRYSTAL-SMD_4P-L2.0-W1.6-BL; LCSC Part C7420782
X3: 32.768KHz; Crystal_SMD_3215-2Pin_3.2x1.5mm; LCSC C95361

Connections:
+3V3: C8.1, C15.1, C18.1, C44.1, C58.1, C68.1, J4.1, R36.2, R38.2, U5.8 (VCC), U6.A22 (VDD), U6.AD14 (VDD), U6.AD23 (VDD), U6.B1 (VDD), U6.W1 (VDD), U6.Y2 (VDDH); also elsewhere on the board
/BAT_CHARGE: U6.K2 (P0.05/AIN3); also elsewhere on the board
/BTN_CANCEL: U6.L1 (P0.06); also elsewhere on the board
/BTN_EXECUTE: U6.G1 (P0.26); also elsewhere on the board
/BUZZER: U6.AD8 (P0.13); also elsewhere on the board
/EPD_BUSY: U6.AC9 (P0.14); also elsewhere on the board
/EPD_CSN: U6.R1 (P1.09/TRACEDATA3); also elsewhere on the board
/EPD_DC: U6.U1 (P0.12/TRACEDATA1); also elsewhere on the board
/EPD_MOSI: U6.H2 (P0.27); also elsewhere on the board
/EPD_RESET: U6.T2 (P0.11/TRACEDATA2); also elsewhere on the board
/EPD_SCK: U6.N1 (P0.08); also elsewhere on the board
/GPIO_1: U6.AD10 (P0.15); also elsewhere on the board
/GPIO_2: U6.AC11 (P0.16); also elsewhere on the board
/GPIO_3: U6.AC15 (P0.19); also elsewhere on the board
/GPIO_4: U6.P2 (P1.08); also elsewhere on the board
/JOY_DOWN: U6.V23 (P1.03); also elsewhere on the board
/JOY_FIRE: U6.W24 (P1.02); also elsewhere on the board
/JOY_LEFT: U6.T23 (P1.05); also elsewhere on the board
/JOY_RIGHT: U6.Y23 (P1.01); also elsewhere on the board
/JOY_UP: U6.U24 (P1.04); also elsewhere on the board
/LORA_BUSY: U6.B11 (P0.28/AIN4); also elsewhere on the board
/LORA_DIO1: U6.A10 (P0.29/AIN5); also elsewhere on the board
/LORA_MISO: U6.B13 (P0.03/AIN1); also elsewhere on the board
/LORA_MOSI: U6.B15 (P1.14); also elsewhere on the board
/LORA_NSS: U6.B17 (P1.12); also elsewhere on the board
/LORA_RF_SW: U6.J1 (P0.04/AIN2); also elsewhere on the board
/LORA_RST: U6.B9 (P0.30/AIN6); also elsewhere on the board
/LORA_SCK: U6.A16 (P1.13); also elsewhere on the board
/MCU_RESETn: J4.10, U6.AC13 (P0.18/NRESET); also elsewhere on the board
/NFC Antenna/NFC1: U6.L24 (P0.09/NFC1); also elsewhere on the board
/NFC Antenna/NFC2: U6.J24 (P0.10/NFC2); also elsewhere on the board
/NRF52840_MCU/DCC: L3.2, U6.B3 (DCC)
/NRF52840_MCU/DEC1: C10.2, U6.C1 (DEC1)
/NRF52840_MCU/DEC2: C14.2, U6.A18 (DEC2)
/NRF52840_MCU/DEC3: C12.2, U6.D23 (DEC3)
/NRF52840_MCU/DEC4: C11.2, C73.1, C74.2, L14.1, U6.B5 (DEC4), U6.E24 (DEC6)
/NRF52840_MCU/DEC5: C13.2, U6.N24 (DEC5)
/NRF52840_MCU/DECUSB: C17.1, U6.AC5 (DECUSB)
/NRF52840_MCU/DIODE_USB_D+: R3.2, U7.1 (I/O1)
/NRF52840_MCU/DIODE_USB_D-: R4.2, U7.3 (I/O2)
/NRF52840_MCU/NRF_USB_D+: R3.1, U6.AD6 (D+)
/NRF52840_MCU/NRF_USB_D-: R4.1, U6.AD4 (D-)
/NRF52840_MCU/P0.20_QSPI_SIO_0: U5.5 (SI/IO0), U6.AD16 (P0.20)
/NRF52840_MCU/P0.21_QSPI_SCK: U5.6 (SCLK), U6.AC17 (P0.21)
/NRF52840_MCU/P0.22_QSPI_SIO_2: U5.3 (~WP/IO2), U6.AD18 (P0.22)
/NRF52840_MCU/P0.23_QSPI_SIO_3: U5.7 (~HOLD/IO3), U6.AC19 (P0.23)
/NRF52840_MCU/P0.24_QSPI_SIO_1: U5.2 (SO/IO1), U6.AD20 (P0.24)
/NRF52840_MCU/P0.25_QSPI_CSN: U5.1 (~CS), U6.AC21 (P0.25)
/NRF52840_MCU/P1.00_SWO: J4.6, R38.1, TP3.1 (1_1), U6.AD22 (P1.00/TRACEDATA0)
/PS_SYNC: U6.AD12 (P0.17); also elsewhere on the board
/QWIIC_SCL: U6.B19 (P1.11); also elsewhere on the board
/QWIIC_SDA: U6.A20 (P1.10); also elsewhere on the board
/USB_D+: U7.6 (I/O1); also elsewhere on the board
/USB_D-: U7.4 (I/O2); also elsewhere on the board
ANT: C7.1, L2.2, U6.H23 (ANT)
BAT_V: U6.A8 (P0.31/AIN7); also elsewhere on the board
BAT_V_READ: U6.M2 (P0.07/TRACECLK); also elsewhere on the board
GND: AE2.2, C2.2, C3.1, C4.1, C5.2, C6.2, C8.2, C10.1, C11.1, C12.1, C13.1, C14.1, C15.2, C16.2, C17.2, C18.2, C44.2, C58.2, C68.2, C73.2, C74.1, J4.3, J4.5, J4.9, NT3.1, R37.1, RF3.2, RF3.3, TP1.1 (1_1), U5.4 (VSS), U6.74 (VSS), U6.B7 (VSS), U7.2 (GND), X1.2, X1.4; also elsewhere on the board
LED_BLUE: U6.A12 (P0.02/AIN0); also elsewhere on the board
LED_GREEN: U6.A14 (P1.15); also elsewhere on the board
LED_RED: U6.P23 (P1.07); also elsewhere on the board
unnamed: AE2.1, R17.1
unnamed: C5.1, L2.1, R17.2, RF3.1
unnamed: L3.1, L14.2
SWDCLK: J4.4, R37.2, TP2.1 (1_1), U6.AA24 (SWDCLK)
SWDIO: J4.2, R36.1, TP4.1 (1_1), U6.AC24 (SWDIO)
VBUS: C16.1, U6.AD2 (VBUS), U7.5 (VBUS); also elsewhere on the board
VSS_PA: C7.2, NT3.2, U6.F23 (VSS_PA)
XC1: C6.1, U6.B24 (XC1), X1.3
XC2: C2.1, U6.A23 (XC2), X1.1
XL1: C3.2, U6.D2 (P0.00/XL1), X3.1
XL2: C4.2, U6.F2 (P0.01/XL2), X3.2

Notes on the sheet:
SWD debug interface
32MHz
RTC clock oscillator
32.768KHz
Bluetooth antenna Implementing: https://www.lcsc.com/datasheet/C127620.pdf
Main MCU Clock oscillator
Power circuit Datasheet: 7.3.5 configuration 5

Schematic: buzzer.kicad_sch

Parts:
BUZZER1: MLT-8530; BUZ-SMD_4P-L8.5-W8.5-P8.50-BR; LCSC Part C94599
C1: 1uF; C_0603_1608Metric; LCSC C5199872
D4: 1N5819WS; D_SOD-323; LCSC C191023
Q3: SI2302_C5296725; SOT-23-3_L2.9-W1.3-P1.90-LS2.4-BR; LCSC C5296725
R39, R40: 1M; R_0402_1005Metric; LCSC C26083
R41, R47: 100; R_0402_1005Metric; LCSC C25076

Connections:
+3V3: BUZZER1.1 (+), D4.1 (K); also elsewhere on the board
/BUZZER: C1.2, R39.1; also elsewhere on the board
GND: BUZZER1.3, BUZZER1.4, Q3.2 (S), R39.2, R40.1; also elsewhere on the board
unnamed: BUZZER1.2, D4.2 (A), R41.2, R47.2
unnamed: Q3.3 (D), R41.1, R47.1
unnamed: C1.1, Q3.1 (G), R40.2

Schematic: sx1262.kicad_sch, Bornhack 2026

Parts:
C22: 470nF; C_0603_1608Metric; LCSC C1623
C24: 100nF; C_0402_1005Metric; LCSC C1525
C25: 47nF; C_0402_1005Metric; LCSC C82219
C26, C29: 47pF; C_0402_1005Metric; LCSC C472454
C27, C28: 1nF; C_0402_1005Metric; LCSC C1523
C30, C50: 1.8pF; C_0402_1005Metric; LCSC C22374861
C31: 3.6pF; C_0402_1005Metric; LCSC C161321; not fitted
C45: 3.3pF; C_0402_1005Metric; LCSC C2941931
C46, C52: C_Small; C_0402_1005Metric; not fitted
C47: 5.6pF; C_0402_1005Metric; LCSC C16193755
C48: 39pF; C_0402_1005Metric; LCSC C86288
C49: 2.2pF; C_0402_1005Metric; LCSC C325452
C51: 2.4pF; C_0402_1005Metric; LCSC C48346
C53: 1uF; C_0603_1608Metric; LCSC C5199872
L5: 15uH; L_0603_1608Metric; LCSC C486329
L6: 47nH; L_0402_1005Metric; LCSC C27151
L7: 2.5nH; L_0402_1005Metric; LCSC C778764
L8: 7.5nH; L_0402_1005Metric; LCSC C98001
L10: 4.7nH; L_0402_1005Metric; LCSC C86065
L11: 0; L_0402_1005Metric; LCSC C17168
L12: 15nH; L_0402_1005Metric; LCSC C381880
R9, R10: 100; R_0402_1005Metric; LCSC C25076
R31, R32: 0; R_0402_1005Metric; LCSC C17168
RF1: A-IPEX1-1.25A; IPEX-SMD_3P-L2.6-W2.6-LS3.0_RF1200001R; LCSC Part C22467595
U2: ZHHXDZ HXCKRF2179MM26-C4; SOT-363-6_L2.0-W1.3-P0.65-LS2.1-BL; LCSC C49010109
U3: SX1262IMLTRT; QFN-24_L4.0-W4.0-P0.50-BL-EP2.6; LCSC Part C191341
X2: S201632M10PF10PPM 32MHz; CRYSTAL-SMD_4P-L2.0-W1.6-BL; LCSC Part C7420782

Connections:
+3V3: C24.2, C53.1, U3.1 (VDD_IN), U3.10 (VBAT), U3.11 (VBAT_IO); also elsewhere on the board
/LORA_BUSY: U3.14 (BUSY); also elsewhere on the board
/LORA_DIO1: U3.13 (DIO1); also elsewhere on the board
/LORA_MISO: U3.16 (MISO); also elsewhere on the board
/LORA_MOSI: U3.17 (MOSI); also elsewhere on the board
/LORA_NSS: U3.19 (NSS); also elsewhere on the board
/LORA_RF_SW: R9.1; also elsewhere on the board
/LORA_RST: U3.15 (NRESET); also elsewhere on the board
/LORA_SCK: U3.18 (SCK); also elsewhere on the board
/SX1262 LoRA/DIO2: R10.1, U3.12 (DIO2)
/SX1262 LoRA/LORA_ANT: C31.1, L8.2; also elsewhere on the board
/SX1262 LoRA/XTA: U3.3 (XTA), X2.1
/SX1262 LoRA/XTB: U3.4 (XTB), X2.3
GND: C22.2, C24.1, C25.2, C26.2, C27.2, C28.2, C30.2, C31.2, C46.1, C47.2, C49.2, C50.1, C52.1, C53.2, RF1.2, RF1.3, U2.2 (GND), U3.2 (GND), U3.5 (GND), U3.8 (GND), U3.20 (GND), U3.25 (GND), X2.2 (GND), X2.4 (GND); also elsewhere on the board
unnamed: C29.1, R31.2
unnamed: C29.2, C30.1, L8.1
unnamed: C45.1, C46.2, L6.2, L7.1, L11.2
unnamed: C45.2, C47.1, C48.1, L7.2
unnamed: C48.2, L10.1
unnamed: R31.1, R32.2, RF1.1
unnamed: C51.1, C52.2, U2.3 (RF1)
unnamed: C49.1, L10.2, U2.1 (RF2)
unnamed: R32.1, U2.5 (RFC)
unnamed: C28.1, R10.2, U2.4 (VC1)
unnamed: C27.1, R9.2, U2.6 (VC2)
unnamed: L5.2, U3.9 (DCC_SW)
unnamed: C51.2, L12.2, U3.22 (RFI_N)
unnamed: C50.2, L12.1, U3.21 (RFI_P)
unnamed: L11.1, U3.23 (RFO)
unnamed: C22.1, L5.1, U3.7 (VREG)
unnamed: C25.1, C26.1, L6.1, U3.24 (VR_PA)

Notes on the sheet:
TODO: Implement the switchless design, because cheaper
Reference design AN1200.54 BOM page 19
DC-DC SW @ 3.25MHz
https://www.ti.com/lit/an/swra496a/swra496a.pdf?ts=1771785552812 Page 35/36 Matching circuit 50 Ohm RF source to antenna
AN1200.91 Layout reference Page 5
Main MCU Clock oscillator
LORA_RF_SW1, LOW = RF2 -> RFC

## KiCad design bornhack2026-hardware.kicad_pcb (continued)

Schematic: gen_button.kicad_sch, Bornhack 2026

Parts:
C60: 100nF; C_0402_1005Metric; LCSC C1525
R19: 10k; R_0402_1005Metric; LCSC C25744
SW6: TS3425PA 160GF 098; KEY-SMD_2P-L6.0-W6.0-P6.00; LCSC Part C115348

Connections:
+3V3: R19.1; also elsewhere on the board
/BTN_EXECUTE: C60.2, R19.2, SW6.2; also elsewhere on the board
GND: C60.1, SW6.1; also elsewhere on the board

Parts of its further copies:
C61: 100nF; C_0402_1005Metric; LCSC C1525
R21: 10k; R_0402_1005Metric; LCSC C25744
SW8: TS3425PA 160GF 098; KEY-SMD_2P-L6.0-W6.0-P6.00; LCSC Part C115348

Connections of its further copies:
+3V3: R21.1; also elsewhere on the board
/BTN_CANCEL: C61.2, R21.2, SW8.2; also elsewhere on the board
GND: C61.1, SW8.1; also elsewhere on the board

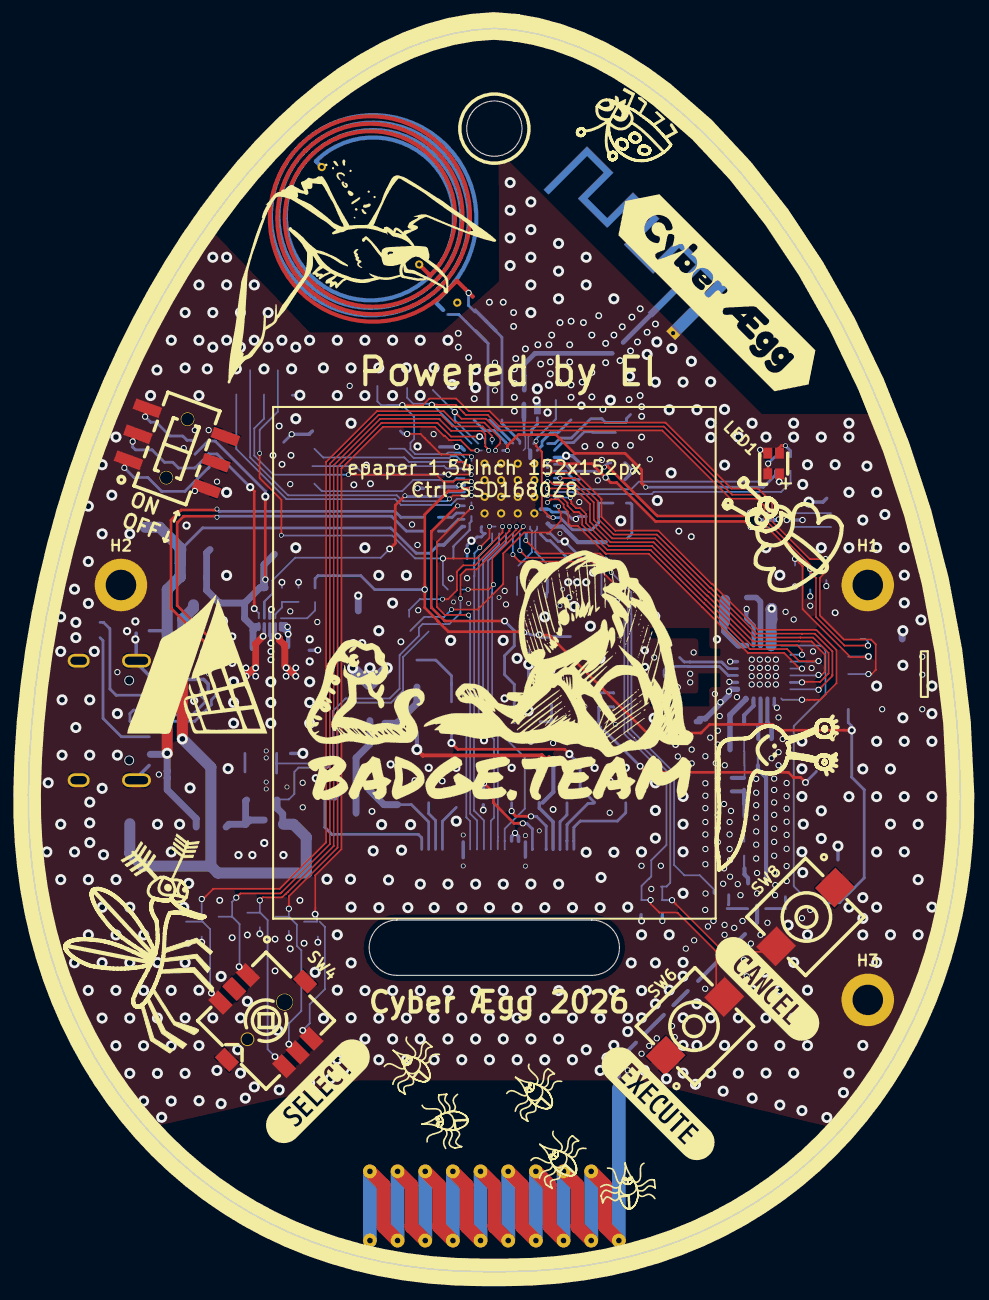
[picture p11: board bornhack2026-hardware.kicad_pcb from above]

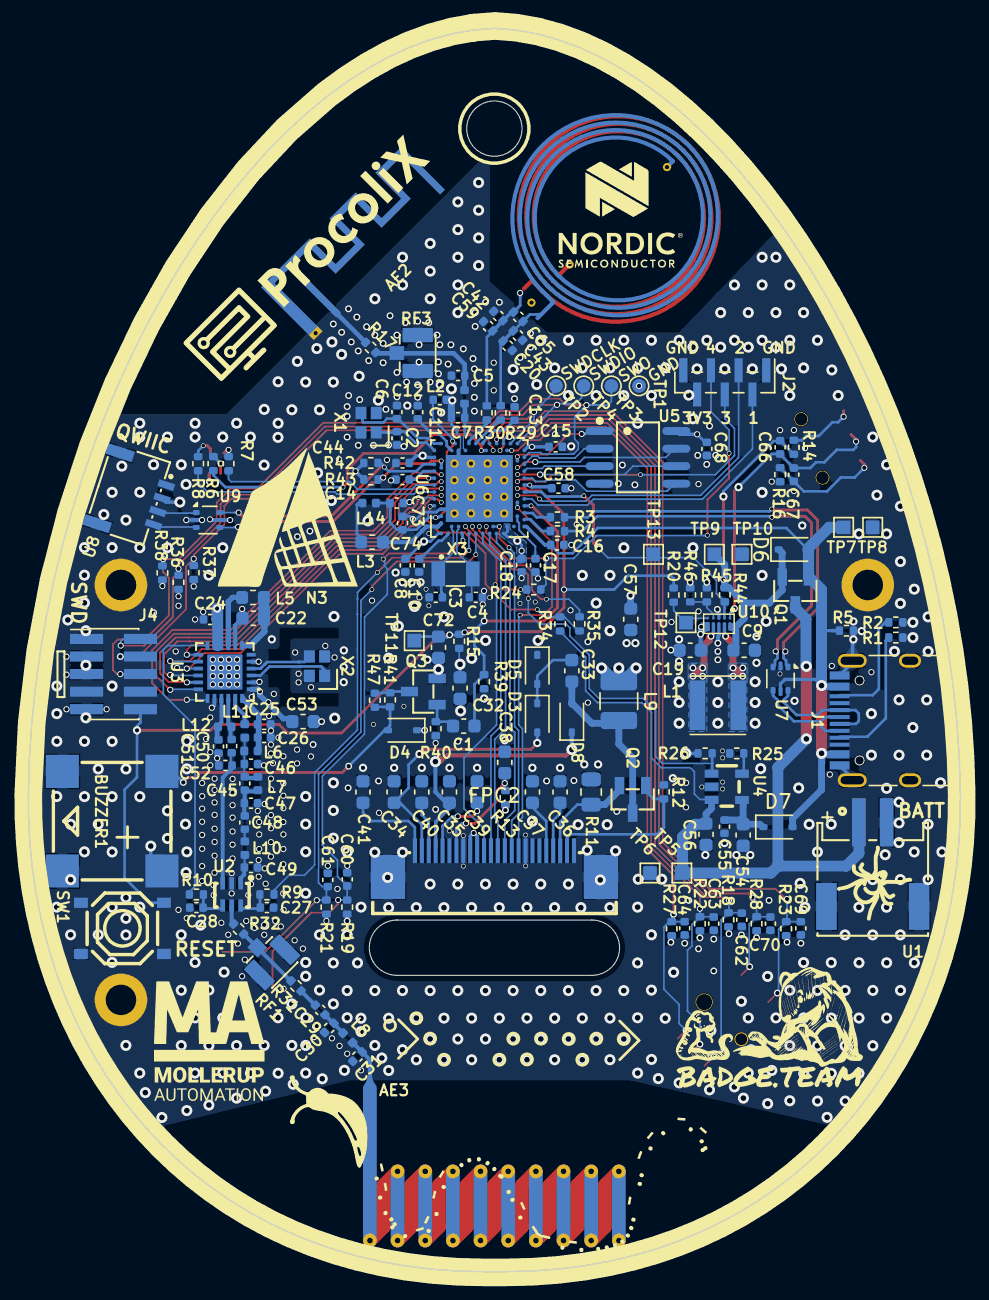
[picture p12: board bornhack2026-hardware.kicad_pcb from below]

Board: 4 copper layers, 67.4 x 89.9 mm, 193 parts (176 on the bottom side), 128 nets.

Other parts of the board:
kibuzzard-697FD34C: G***; kibuzzard-697FD34C
kibuzzard-697FD37D: G***; kibuzzard-697FD37D
kibuzzard-697FD333: G***; kibuzzard-697FD333
kibuzzard-69569E9F: G***; kibuzzard-69569E9F

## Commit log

2025-12-24 Added luxury schematic for sx1262
    [bornhack2026-hardware.kicad_sch, sx1262.kicad_sch]
2025-12-25 Fixed mistake in NRF52 footprint, add NAND FLASH, add NFC antenna schematic.
    [bornhack2026-hardware.kicad_pcb, bornhack2026-hardware.kicad_sch, display.kicad_sch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]
2025-12-26 Add original tamagotchi buttons to schematic.
    [bornhack2026-hardware.kicad_pcb, bornhack2026-hardware.kicad_sch, gen_button.kicad_sch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]
2025-12-26 PCB layout egg shape, for reference.
    [bornhack2026-hardware.kicad_pcb, bornhack2026-hardware.kicad_sch, display.kicad_sch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]
2025-12-27 Switched the LC filters from ceramic LoRa filter.
    [bornhack2026-hardware.kicad_pcb, bornhack2026-hardware.kicad_sch, display.kicad_sch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]
2025-12-28 Progress, routed more stuff.
    [bornhack2026-hardware.kicad_pcb, bornhack2026-hardware.kicad_sch, display.kicad_sch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]
2025-12-29 Bluetooth antenna should work better, NFC has IPEX for tuning.
    [bornhack2026-hardware.kicad_pcb, bornhack2026-hardware.kicad_sch, input.kicad_sch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]
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2025-12-29 Redid the sx1268 RF circuit for the layout to comply with the datasheet.
    [bornhack2026-hardware.kicad_pcb]
2025-12-29 small fixes.
    [bornhack2026-hardware.kicad_pcb]
2025-12-30 Routed buttons to MCU.
    [bornhack2026-hardware.kicad_pcb, bornhack2026-hardware.kicad_sch, input.kicad_sch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]
2025-12-30 Fixed DRC errors, added bunch of stitch through vias.
    [bornhack2026-hardware.kicad_pcb]
2025-12-30 Fix tiny issues, add more vias.
    [bornhack2026-hardware.kicad_pcb, bornhack2026-hardware.kicad_sch, nrf52840_mcu.kicad_sch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]
2025-12-31 Moved SMA-connector Lora for VNA testing.
    [bornhack2026-hardware.kicad_pcb, bornhack2026-hardware.kicad_sch]
2026-01-01 WIP: Moved buttons, battery.
    [bornhack2026-hardware.kicad_pcb, bornhack2026-hardware.kicad_sch, nrf52840_mcu.kicad_sch]
2026-01-01 Connected up buttons, labeled buttons, added some via stitching.
    [bornhack2026-hardware.kicad_pcb, bornhack2026-hardware.kicad_sch, gen_button.kicad_sch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]
2026-01-01 Add JTAG 2.54mm header footprint.
    [bornhack2026-hardware.kicad_pcb, nrf52840_mcu.kicad_sch]
2026-01-01 Remove mounting hole REFDES.
    [bornhack2026-hardware.kicad_pcb, bornhack2026-hardware.kicad_sch]
2026-01-01 Add missing board edge symbol.
2026-01-01 Check & fix MCU schematic
    [nrf52840_mcu.kicad_sch]
2026-01-02 Processed the unconnected pads in the NRF52 Renze found, Added the IPEX connector to allow tuning of the Bluetooth antenna, moved the RESET button.
    [bornhack2026-hardware.kicad_pcb, nrf52840_mcu.kicad_sch]
2026-01-02 Moved battery connector out of the way of the battery.
    [bornhack2026-hardware.kicad_pcb, input.kicad_sch, nrf52840_mcu.kicad_sch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]
2026-01-02 Checked PCBA for JLCPCB.
    [bornhack2026-hardware.kicad_pcb, bornhack2026-hardware.kicad_sch, cyber-egg-v1.0_bom.csv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]
2026-01-03 Changed antennas for PCB antennas, move stuff because of it.
    [bornhack2026-hardware.kicad_pcb, bornhack2026-hardware.kicad_sch, nrf52840_mcu.kicad_sch]
2026-01-03 Changed NFC coil + tune C's to match better with datasheet.
    [bornhack2026-hardware.kicad_pcb, bornhack2026-hardware.kicad_sch, display.kicad_sch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]
2026-01-04 Moved LoRa radio closer to antenna
    [bornhack2026-hardware.kicad_pcb, bornhack2026-hardware.kicad_sch, cyber-egg-v1.1_bom.csv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]
2026-01-04 Remove old prod files.
    [cyber-egg-v1.1_bom.csv, cyber-egg-v1.1_designators.csv, cyber-egg-v1.1_positions.csv]
2026-01-04 Added small Bornhack logo.
    [bornhack2026-hardware.kicad_pcb, bornhack2026-hardware.kicad_sch]
2026-01-04 Fix display connector 3D model
    [bornhack2026-hardware.kicad_pcb]
2026-01-04 Fix screen outline (that I broke), add epaper 3D model back in, move flat cable hole down a bit.
    [bornhack2026-hardware.kicad_pcb]
2026-01-04 Squashed in new battery connector, made NFC coil and Bluetooth fit as good and bad as possible.
    [bornhack2026-hardware.kicad_pcb, bornhack2026-hardware.kicad_sch, nrf52840_mcu.kicad_sch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]
2026-01-04 Clean up NFC connection.
    [bornhack2026-hardware.kicad_pcb]
2026-01-04 Fixed missing NRF52 3D object and missing connection.
    [bornhack2026-hardware.kicad_pcb]
2026-01-04 Add QWIIC connector to design.
    [bornhack2026-hardware.kicad_pcb, bornhack2026-hardware.kicad_sch, qwiic.kicad_sch]
2026-01-06 Replaced joystick with alternatie (cheaper) part.
    [bornhack2026-hardware.kicad_pcb, bornhack2026-hardware.kicad_sch, input.kicad_sch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]
2026-01-06 Add batteryvoltage and charge indicator circuit.
    [bornhack2026-hardware.kicad_pcb, bornhack2026-hardware.kicad_sch, nrf52840_mcu.kicad_sch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]
2026-01-07 Fixed schematic enspect errors. Fixed jhaand name in silk screen.
    [bornhack2026-hardware.kicad_pcb, bornhack2026-hardware.kicad_sch, power.kicad_sch]
2026-01-07 Added some PCB art.
    [bornhack2026-hardware.kicad_pcb]
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2026-01-07 Add Readme, fix labels in schematic.
    [bornhack2026-hardware.kicad_pcb, bornhack2026-hardware.kicad_sch, input.kicad_sch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]
2026-01-09 10-pin SWD interface added.
    [bornhack2026-hardware.kicad_pcb, nrf52840_mcu.kicad_sch]
2026-01-10 Moved SWR connector to other side of board, reversed on/off switch UP -> ON.
    [bornhack2026-hardware.kicad_pcb, bornhack2026-hardware.kicad_sch, input.kicad_sch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]
2026-01-10 Fixed PCBA rotations in using component property.
    [bornhack2026-hardware.kicad_pcb, bornhack2026-hardware.kicad_sch, display.kicad_sch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]
2026-01-10 Fix missing epaper display in 3D models.
    [bornhack2026-hardware.kicad_pcb]
2026-01-12 Added buzzer to the design.
    [bornhack2026-hardware.kicad_pcb, bornhack2026-hardware.kicad_sch, buzzer.kicad_sch]
2026-01-13 Add Readme text, fixed some stuff in the design again, pull-ups externally on the I2C bus.
    [bornhack2026-hardware.kicad_pcb, qwiic.kicad_sch]
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2026-01-19 Fixed DRC errors, added the game.
    [bornhack2026-hardware.kicad_pcb, bornhack2026-hardware.kicad_sch]
2026-01-19 Fixed nmos part that was not sufficiently in stock at LCSC.
    [bornhack2026-hardware.kicad_pcb, buzzer.kicad_sch]
2026-01-24 Replaced schottky diode with 1A version, fixed joystick footprint.
    [bornhack2026-hardware.kicad_pcb, bornhack2026-hardware.kicad_sch, buzzer.kicad_sch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]
2026-01-25 Diodes in spec now for the display driver.
    [bornhack2026-hardware.kicad_pcb, bornhack2026-hardware.kicad_sch, buzzer.kicad_sch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]
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2026-02-12 Add ESD protoction to USB-C, small fixes
    [bornhack2026-hardware.kicad_pcb, display.kicad_sch, nfc-antenna.kicad_sch]
2026-02-16 Improvements, now need to know the specs for the new display module.
    [bornhack2026-hardware.kicad_pcb, sx1262.kicad_sch]
2026-02-19 Switched to recycled e-ink screen, using the Tanoshii measuremens and distances.
    [bornhack2026-hardware.kicad_pcb, bornhack2026-hardware.kicad_sch, display.kicad_sch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]
2026-02-19 Fixed net names of changed pins
    [bornhack2026-hardware.kicad_pcb, bornhack2026-hardware.kicad_sch]
2026-02-21 Changed out RF switch and display connector for parts that are stil available.
    [bornhack2026-hardware.kicad_pcb, cyber-egg-2025-02-20_bom.csv, cyber-egg-2025-02-20_designators.csv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]
2026-02-21 Fix power supply, use PG signal to hold reset until the power is stable.
    [bornhack2026-hardware.kicad_pcb, bornhack2026-hardware.kicad_sch, power.kicad_sch]
2026-02-22 Fixed schematic to have 0 DRC errors, changed display connector.
    [bornhack2026-hardware.kicad_pcb, bornhack2026-hardware.kicad_sch, display.kicad_sch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]
2026-02-22 Fixed some more DRC errors in PCB.
    [bornhack2026-hardware.kicad_pcb]
2026-02-23 Add MA logo, test points, tuned RF LoRa.
    [bornhack2026-hardware.kicad_pcb, bornhack2026-hardware.kicad_sch, input.kicad_sch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]
2026-02-26 Artwork added, minor rework on the LoRa rf component placement.
    [bornhack2026-hardware.kicad_pcb, bornhack2026-hardware.kicad_sch]
2026-02-26 dotting the i's , list checks before V2 order.
    [bornhack2026-hardware.kicad_pcb, display.kicad_sch, input.kicad_sch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]
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2026-03-08 Updated readme.md for Prototype V2. Simplified NRF IO net names.
    [bornhack2026-hardware.kicad_pcb, bornhack2026-hardware.kicad_sch, buzzer.kicad_sch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]
2026-03-14 Prototype V2 hardware fixes, clearance SWD port, move display up. Add seagull to front silkscreen.
    [bornhack2026-hardware.kicad_pcb]
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2026-04-25 Prototype V3, speaker resistor 50 ohm, 500ohm on to second pad epd
    [bornhack2026-hardware.kicad_pcb, bornhack2026-hardware.kicad_sch, buzzer.kicad_sch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]
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2026-06-20 Fixed version, badger back in cage.
    [bornhack2026-hardware.kicad_pcb]
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2026-07-26 Fix QWIIC connector polarity, update flatflex connector.
    [bornhack2026-hardware.kicad_pcb, qwiic.kicad_sch]
